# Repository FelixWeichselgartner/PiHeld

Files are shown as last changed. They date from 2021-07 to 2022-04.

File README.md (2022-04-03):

# PiHeld

This project is the first Raspberry Pi based handheld console to include a GameBoy cartridge reader.

The PCBs are under active testing and will a working prototype should be available soon. Be a bit more patient of you want to use the PCBs ;).

## Preview

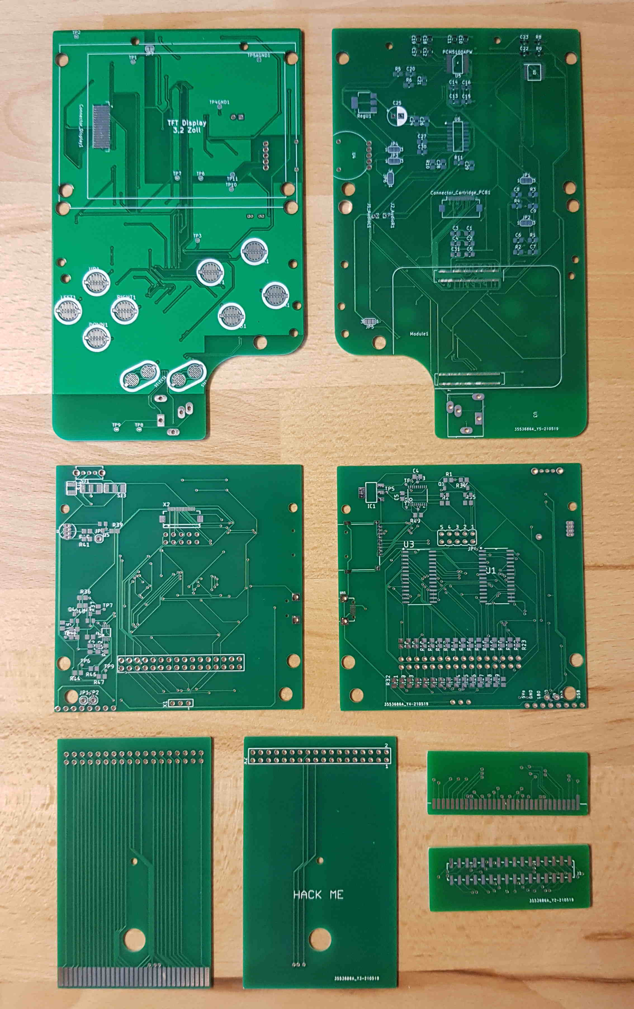
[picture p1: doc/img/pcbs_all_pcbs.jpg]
all_pcbs


## Build guide

TODO: Here include all parts and how to build the system.

## Developer information

For Documentation check out [this](./doc/).

TODO: Here include information needed for developers.

# Further improvements (to-do list):

* Add a HDMI (or Mini-HDMI) Connector to the CM4 (on display-pcb) to give the user a Nintendo Switch like experience.
* Make a version compatible with the Raspberry Pi Zero, as it is cheaper and more commonly used.
* Make a version that fits in a GameBoy Color/Pocket shell. As those only have one pcb inside, the display and cartridge pcb could be combined to a single pcb. This would make the production part significantly easier.
* Make the USB-Charging port bidirectional. This enables users to connect e.g. a keyboard to the device (USB OTG).
* Update the software to enable users to interface with GameBoy Color cartridges.
* Theoretically GameBoy Advance cartridges could also be used with the system. Maybe some minor hardware modifications would be needed for this. Also the GBA cartridges do not fit in the GB/GBC/GBP cartridge slot.
* Make a custom OS-Image that already features the needed modifications for the hardware.
* Cartridge-pcb version with MCP23S17, as SPI is a lot faster than I²C.

## License

This project is completely open source, as we want everybody to be able to build their own PiHeld. Check out the `License.md` file to get further information on licensing.

## Split-off projects

* https://github.com/FelixWeichselgartner/Arduino_Logic_Analyzer
* https://github.com/FelixWeichselgartner/Adafruit_PowerBoost_SaveShutdown
* https://github.com/FelixWeichselgartner/RPi-I2C-LevelShifter
* https://github.com/FelixWeichselgartner/rpi-mcp23017

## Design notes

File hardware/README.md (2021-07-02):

## Hardware

Just like the original GameBoy there are two pcbs on which all the components are placed.

### Mapping of the functionalities
* Display-PCB
    * Compute Module 4
    * Display
    * Audio
    * Buttons
* Cartridge-PCB
    * Connectors (MicroUSB, MicroSD, ...)
    * Power Management (LiPo, charger, ...)
    * Cartridge dumper
    * Save shutdown circuit
    * ADC for battery percentage
    * optional IC for fast level shifting

### FFC Connection

The two pcbs are connected with a ffc. This is how the 18 pins are used:
* 1 - 5V - power supply of Cartridge-PCB
* 2 - 5V - power supply of Cartridge-PCB
* 3 - 5V - power supply of Cartridge-PCB
* 4 - 5V - power supply of Cartridge-PCB
* 5 - SDA - I²C-Data of cm4
* 6 - SCL - I²C-CLK of cm4
* 7 - 3.3V - digital 3.3V power supply provided by cm4
* 8 - CD/DAT3/CS - SD-Card
* 9 - DAT2/RSV - SD-Card
* 10 - DAT1/RSV - SD-Card
* 11 - DAT0/DO - SD-Card
* 12 - CLK/SCLK - SD-Card
* 13 - CMD/DI - SD-Card
* 14 - Shutdown - shutdown signal for cm4
* 15 - GND - Ground of Cartridge-PCB
* 16 - GND - Ground of Cartridge-PCB
* 17 - GND - Ground of Cartridge-PCB
* 18 - GND - Ground of Cartridge-PCB

### Buying links

Alls links are just suggestions (mostly the parts I ordered) and may not be valid anymore. I have no affiliation to any platform linked below.

#### General
* The PCBs
* GameBoy shell: https://de.aliexpress.com/item/4001165606660.html?spm=a2g0s.9042311.0.0.27424c4dcSplCO
* FPC-Connector (18P): https://de.aliexpress.com/item/32956902542.html?spm=a2g0s.9042311.0.0.27424c4dpEIIFD
* FFC: https://de.aliexpress.com/item/10000012558629.html?spm=a2g0s.9042311.0.0.27424c4dpEIIFD
* 0805 Resistors and Capacitors

#### Cartridge-PCB
* MicroSD-Card-Adapter: https://de.aliexpress.com/item/4001278357176.html?spm=a2g0s.9042311.0.0.27424c4dHRu5rN
* MicroUSB-Adapter: https://de.aliexpress.com/item/4000774276762.html?spm=a2g0s.9042311.0.0.27424c4dHRu5rN
* LiPo-Battery: https://de.aliexpress.com/item/4000687003747.html?spm=a2g0s.9042311.0.0.27424c4dHRu5rN
* GameBoy Cartridge Adapter: https://de.aliexpress.com/item/4000290191316.html?spm=a2g0s.9042311.0.0.27424c4dcSplCO
* Power switch: https://de.aliexpress.com/item/32920574638.html?spm=a2g0s.9042311.0.0.27424c4dj7Khsc
* 2N7002: https://de.aliexpress.com/item/2029421500.html?spm=a2g0s.9042311.0.0.27424c4dj7Khsc
* RGB-LED: https://de.aliexpress.com/item/32885829414.html?spm=a2g0s.9042311.0.0.27424c4dpEIIFD
* ADS1015: https://de.aliexpress.com/item/4001177538119.html?spm=a2g0s.9042311.0.0.27424c4dpEIIFD
* Male SMD Header: https://de.aliexpress.com/item/32954771384.html?spm=a2g0s.9042311.0.0.27424c4dpEIIFD
* TXB0108PWR: https://de.aliexpress.com/item/1005001823871461.html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
* MCP23017-E/SO: https://de.aliexpress.com/item/1005001802509822.html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

#### Cartridge-PCB Tester (Optional)
* GameBoy Cartridge shell: https://de.aliexpress.com/item/1005001278227724.html?spm=a2g0s.9042311.0.0.27424c4dHRu5rN
* Male Headers with 2.54mm

#### Display-PCB
* Display: https://de.aliexpress.com/item/4000654251979.html?spm=a2g0s.9042311.0.0.27424c4dpEIIFD
* XPT2046: https://de.aliexpress.com/item/32790065511.html?spm=a2g0s.9042311.0.0.3aed4c4dYS9Rbq
* PCM5100A: https://de.aliexpress.com/item/1005002119447863.html?spm=a2g0s.9042311.0.0.3aed4c4dYS9Rbq
* Volume Wheel: https://de.aliexpress.com/item/1005001442108461.html?spm=a2g0s.9042311.0.0.27424c4dHRu5rN
* GameBoy speaker: https://de.aliexpress.com/item/33033843204.html?spm=a2g0s.9042311.0.0.27424c4dcSplCO
* Compute Module 4 Adapter: https://de.aliexpress.com/item/1005002168314176.html?spm=a2g0s.9042311.0.0.27424c4dj7Khsc
* PAM8403: https://de.aliexpress.com/item/1005001577722596.html?spm=a2g0s.9042311.0.0.27424c4dUdkYGC
* FPC-Connector for display: https://de.aliexpress.com/item/1005002212273725.html?spm=a2g0s.9042311.0.0.27424c4d8n1T4b
* Headphone jack with plug switch: https://de.aliexpress.com/item/4000465185208.html?spm=a2g0o.cart.0.0.33b33c00diKgb9&mp=1

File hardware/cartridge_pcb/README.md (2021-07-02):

# Cartridge PCB

The cartridge pcb includes the following:
* Connectors
    * Micro USB Connector
    * SD-Card Connector
* Power Management
    * Power-Switch
    * RGB-Led (charging/low-battery/fully-charged)
    * LiPo connector
    * LiPo-BoostUp connector
* Cartridge dumper
    * 2x MCP23017 for cartridge
* Save shutdown circuit
* ADC for battery percentage
* optional IC for fast level shifting

### Schematic

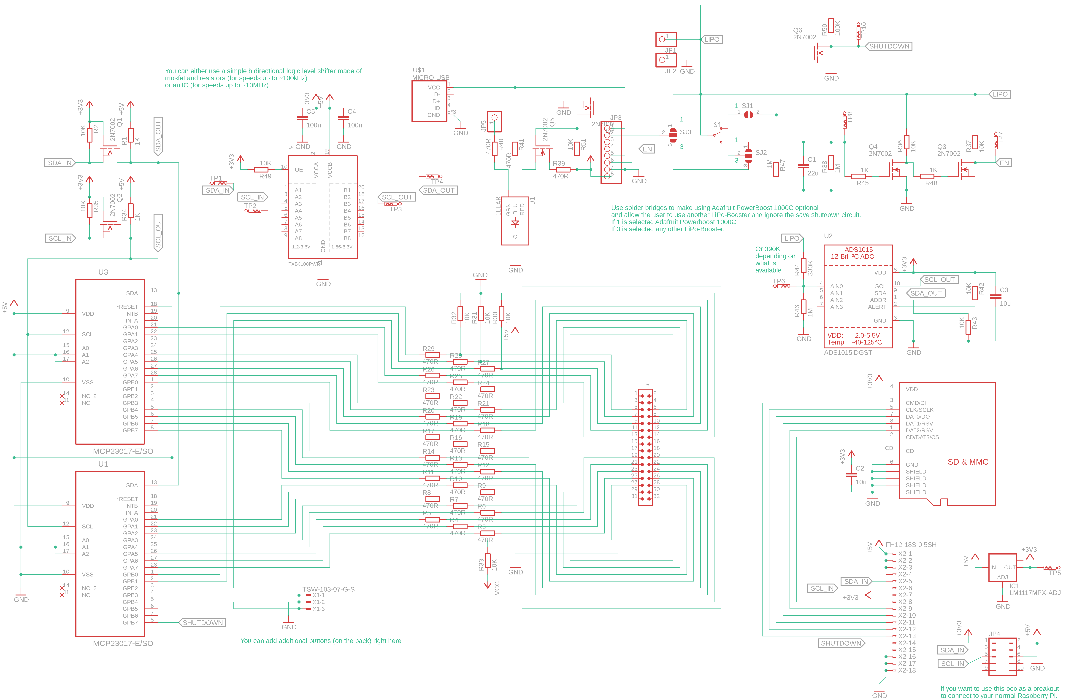
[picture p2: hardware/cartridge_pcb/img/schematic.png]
schematic


### Layout

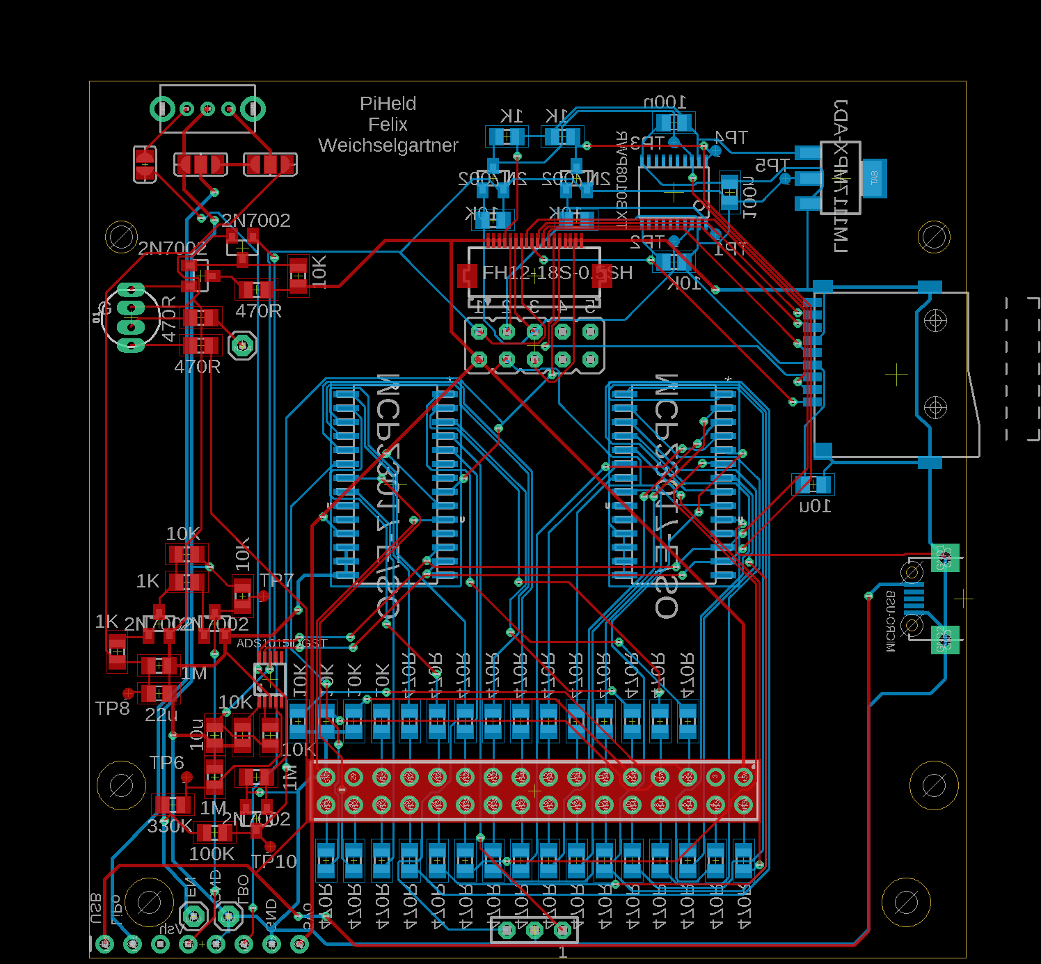
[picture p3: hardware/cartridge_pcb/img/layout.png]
layout


### Gerber Preview

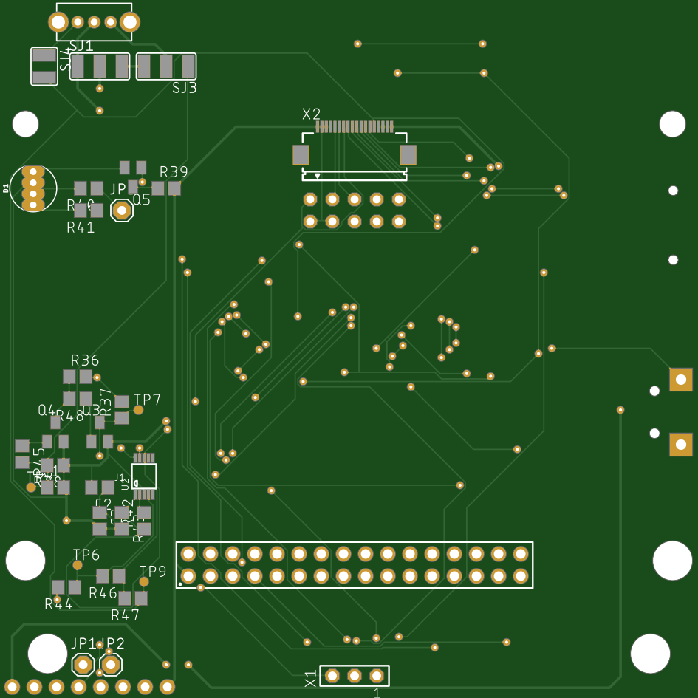
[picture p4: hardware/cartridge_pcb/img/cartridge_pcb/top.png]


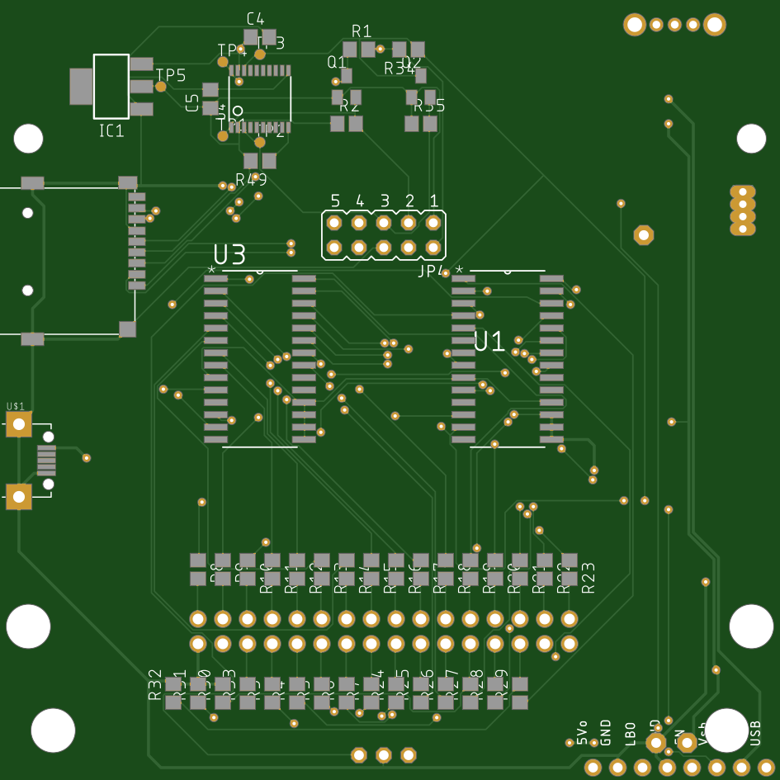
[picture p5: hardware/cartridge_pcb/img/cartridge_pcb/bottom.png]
gerber_bottom


### Breakout board for cartridge adapter to adjust height for gameboy shell

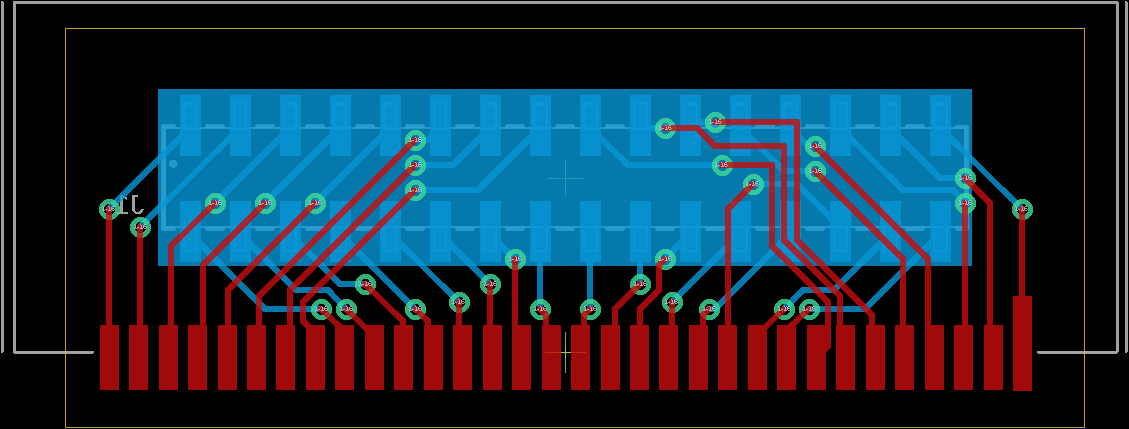
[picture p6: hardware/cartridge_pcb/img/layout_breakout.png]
layout_breakout


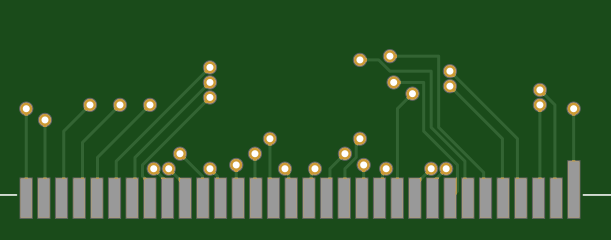
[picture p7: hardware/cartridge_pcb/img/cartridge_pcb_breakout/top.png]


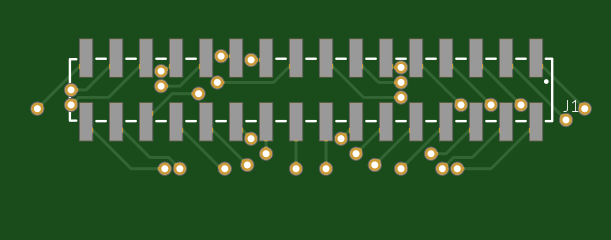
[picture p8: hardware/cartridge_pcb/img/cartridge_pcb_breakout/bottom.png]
gerber_bottom


## License

Creative Commons Attribution-ShareAlike 4.0 International License (see `LICENSE` file).

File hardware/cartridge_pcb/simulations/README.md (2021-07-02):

# Simulations

## Save Shutdown Circuit

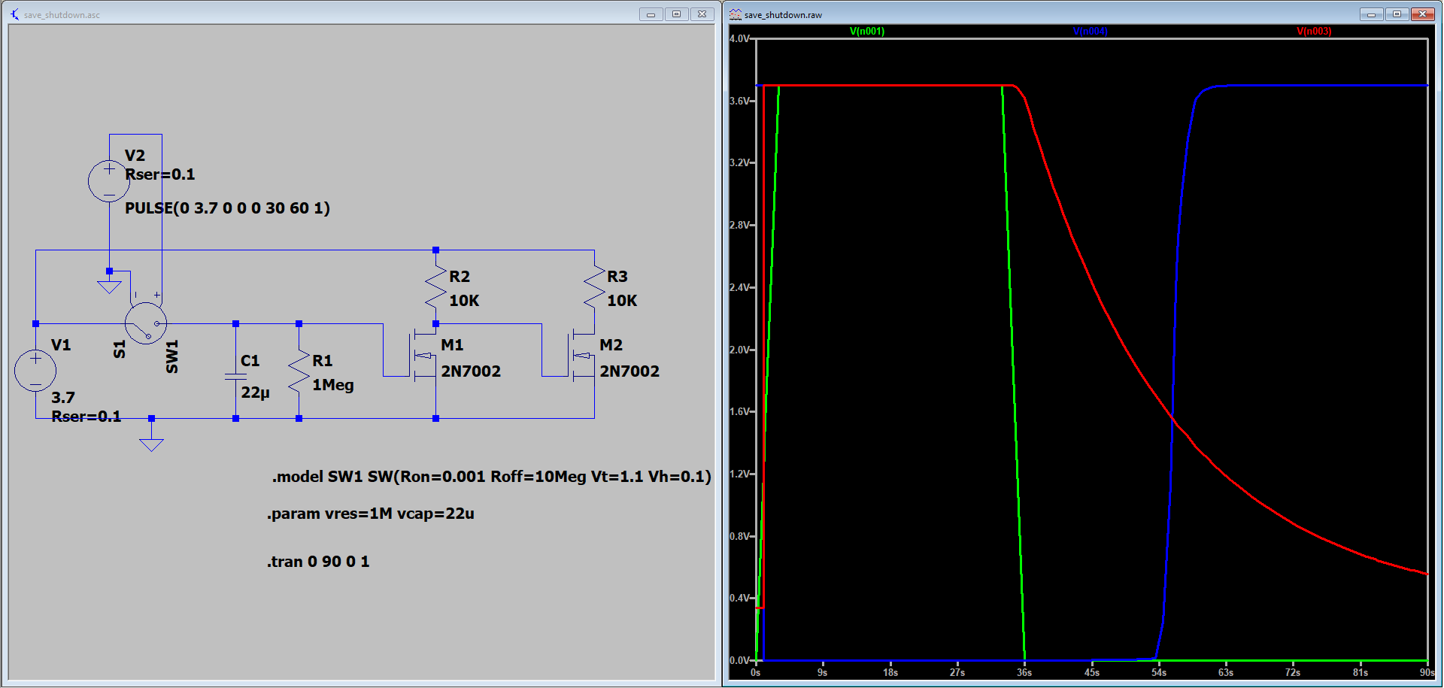
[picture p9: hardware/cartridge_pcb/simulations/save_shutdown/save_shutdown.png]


## I²C Level Shifter

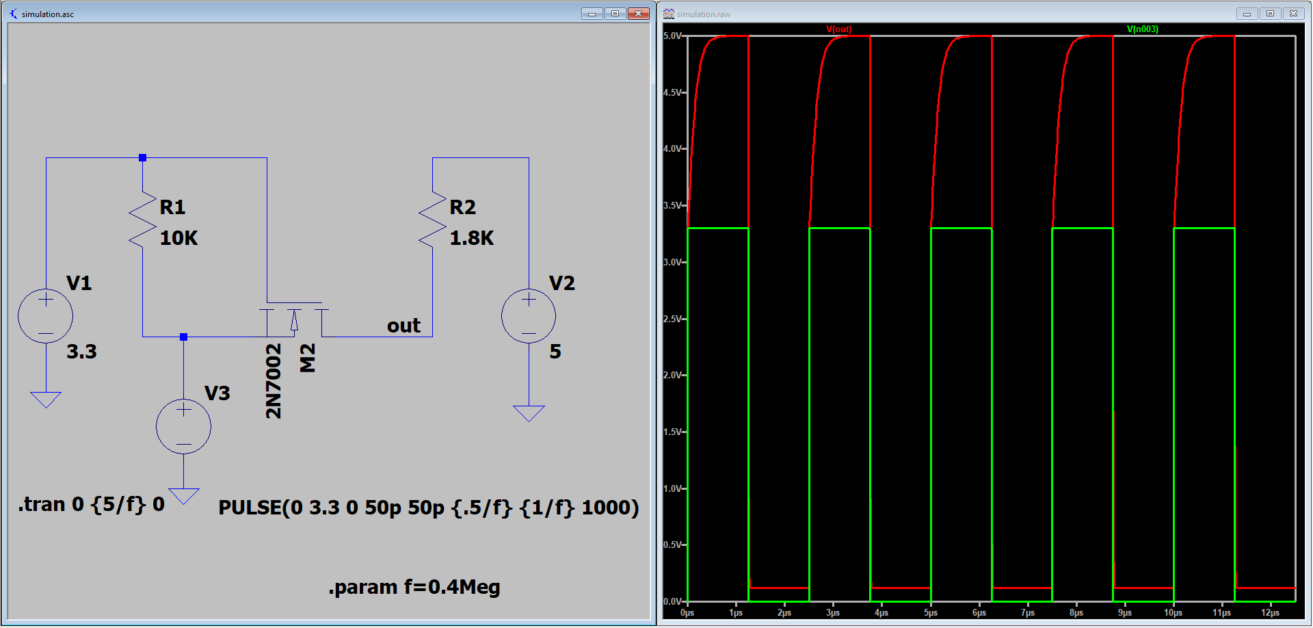
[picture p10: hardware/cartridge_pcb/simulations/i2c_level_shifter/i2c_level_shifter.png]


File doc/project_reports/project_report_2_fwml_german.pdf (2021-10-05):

# FAKULTÄT ELEKTROTECHNIK UND WIRTSCHAFTSINGENIEURWESEN

HOCHSCHULE FÜR ANGEWANDTE WISSENSCHAFTEN LANDSHUT

Projektbericht im Modul Eingebettete autonome Systeme I zum Thema

## Entwicklung einer Raspberry Pi basierten Handheld-Konsole mit eingebettetem GameBoy Cartridge Reader II

Autor: | Felix Weichselgartner, Matthias Lohberger
Betreuer: | Prof. Dr.-Ing. Mathias Rausch
Eingereicht: | 09.07.2021
Aktualisierte Version: 05.10.2021

Hiermit erklären wir, dass wir die Arbeit selbständig verfasst, noch nicht anderweitig für Prüfungszwecke vorgelegt, keine anderen als die angegebenen Quellen oder Hilfsmittel benützt sowie wörtliche und sinngemäße Zitate als solche gekennzeichnet haben.

Tiefenbach, 09.07.2021 | Felix Weichselgartner, Matthias Lohberger

## Acknowledgments

We want to thank the Open Source and GameBoy community, who made this project possible.

## Abstract

A popular project in the internet community is the „GameBoy Zero“. Here a Raspberry Pi (RPi) Zero [1] (with buttons, battery, power electronics, display, etc.) is integrated in the shell of an original GameBoy. This result in a RPi based handheld game console, that can emulate games from various systems. More about the history of the project can be found here [2]. The new contribution to the project is the embedded cartridge reader, which makes it possible to interact with real GameBoy cartridges. Therefore, it is not necessary to download ROMs from dubious websites and you are able to use your real GameBoy cartridges and emulate them, all in one device.
In this work, the design of a replacement GameBoy mainboard is continued. The pcb will be extended with components essential for an autonomous embedded system (e.g. LiPo-Battery, LiPo-Charger, Boost-Converter, ...). Furthermore, a replacement display pcb will be developed, which acts as a carrier board for a RPi Compute Module 4 (CM4). The CM4 used instead of the RPi Zero to get more calculating power, which enables the user to play more demanding games.

iii

## Inhaltsverzeichnis

Acknowledgments | ii
Abstract | iii
1 Motivation | 1
2 Grundlagen | 2
3 Implementierung | 10
4 Testen | 32
5 Ergebnisse | 34
Literaturverzeichnis | 36
Abbildungsverzeichnis | 39

iv

Inhaltsverzeichnis

Tabellenverzeichnis | 41

v

## 1 Motivation

### 1.1 Problemstellung

Ende 2018 wurde ich auf ein populäres Elektronikprojekt namens „GameBoy Zero“ [2] aufmerksam. Im Laufe der nächsten Monate, baute ich meine eigene Version [3], womit ich schlussendlich verschiedene Systeme auf einem RPi Zero [1] emulieren konnte. Der Haken ist jedoch, sofern man nicht seine eigenen GameBoy-Spiele auslesen kann, ist man auf sogenannte ROMs aus dem Internet angewiesen. Diese beinhalten den ausgelesenen Read Only Memory (ROM)-Speicher der GameBoy-Cartridges, womit das Spiel emuliert werden kann [4]. Dies führte dazu, dass ich Mitte 2019 einen Catridge-Reader [5] baute, welcher es mir ermöglichte, meine eigenen Catridges auszulesen. Hierbei kann aber nicht nur der ROM ausgelesen werden, sondern auch der Random Access Memory (RAM), welcher den Speicherstand der Spiele enthält. Das Problem hierbei ist jedoch, dass dies zwei separate Geräte und nicht wie beim originalen GameBoy in einem Gerät vereint sind.

### 1.2 Zielsetzung

In dieser Arbeit wird das Design einer Ersatzplatine des Mainboards für den Klassischen GameBoy (DMG) fortgeführt. Die Platine wird um Komponenten erweitert, welche essenziell für ein eingebettetes autonomes System sind (z.B. LiPo-Batterie, LiPo-Ladeschaltung, Aufwärtswandler, ...). Des Weiteren wird eine Ersatzplatine für die Display-Platine des DMG entwickelt, welche u.a. als Trägerplatine für ein RPi CM4 dient. Das CM4 wird anstatt eines RPi Zero verwendet, um mehr Rechenleistung für aufwändigere Spiele zur Verfügung zu haben.

1

## 2 Grundlagen

### 2.1 GameBoy

Der DMG hatte zwei Platinen. Die obere Platine (jeweils links in Abbildung 2.1) enthält im Wesentlichen das Display, Audio und die Buttons. Daher wird die Ersatzplatine im Folgenden Display-PCB genannt. Die untere Platine (jeweils rechts in Abbildung
2.1) enthält die CPU und die Cartridge-Schnittstelle. Der Ersatz für diese Platine wird daher im Folgenden Cartridge-PCB genannt.

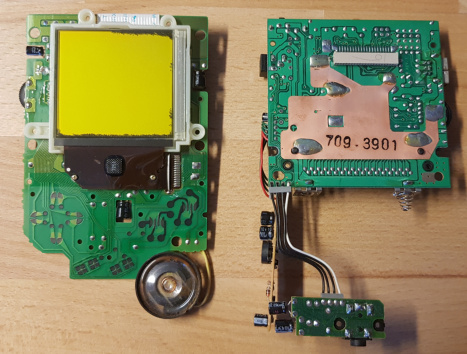
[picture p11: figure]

(a) Oberseiten der Platinen | (b) Unterseiten der Platinen
Abbildung 2.1: DMG Platinen

### 2.2 Raspberry Pi Compute Module 4

Das RPi CM4 [6] ist ein sog. „System on Module (SoM)“ welches die Kernkomponenten eines RPi auf einer kleinen aufsteckbaren Platine enthält. Sämtliche Anschlüsse für Peripheriegeräte werden auf dem sog. „Carrier-Board“ verbaut und über die Steckverbindungen leitend mit dem CM4 verbunden. Als Entwicklungsplatine wird von der Raspberry Pi Foundation das sog. „Raspberry Pi Compute Module 4 IO Board“
[7] vertrieben, welches die Spannungsversorgung, Anschlüsse für Peripheriegeräte (z.
B. HDMI, PCIe, USB, GPIO-Pins, MicroSD-Karte, ...) und weitere Funktionen enthält. Auf dieses kann das CM4 aufgesteckt werden und danach ähnlich zu einem RPi 4

2

### 2 Grundlagen

verwendet werden. Hierbei ist zu beachten, dass das CM4 nur lose auf dem RPi 4 basiert. Dementsprechend ist die Rechenleistung und Leistungsaufnahme vergleichbar, jedoch nicht identisch.

https://www.jeffgeerling.com/sites/default/files/images/raspberry-pi-model-sizecomparison.jpg

Abbildung 2.2: Vergleich verschiedener RPi Modelle [8]

In Abbildung 2.2 werden verschiedene RPi Modelle gezeigt. Neben dem bisher für den Einsatz geplanten RPi Zero W, wird das CM4 gezeigt, sowie das Vorgängermodell Compute Module 3 (CM3). Des Weiteren wird noch ein RPi 4 (Model B) gezeigt, wobei auffällt, dass dieses signifikant größer ist als die anderen Modelle (sowohl in Höhe als auch in Länge und Breite). Der wesentliche Unterschied zwischen dem Compute Module und dem RPi Zero W ist die Rechenleistung und die Leistungsaufnahme. Besonders das CM4 hat wesentlich mehr Rechenleistung als der RPi Zero W, weshalb die Leistungsaufnahme beim CM4 entsprechend höher ist. Beide Modelle wären somit für den Einsatz geeignet. Hier wurde die Entscheidung getroffen ein CM4 aufgrund der hohen Rechenleistung zu verwenden. Eine detaillierte Analyse des CM4 kann in
[8] gefunden werden.
Ein Vergleich der Rechenleistung verschiedener RPi Modelle kann in Abbildung 2.3 und ein Vergleich der Leistungsaufnahme in Abbildung 2.4 gefunden werden. In [9] werden mehrere RPi Modelle anhand verschiedener Parameter verglichen.

https://rpi-magazines.s3-eu-west-1.amazonaws.com/magpi/legacyassets/2019/06/2019-06-21-15_40_11-Window.png

Abbildung 2.3: Vergleich der Rechenleistung verschiedener RPi Modelle [9]

https://rpi-magazines.s3-eu-west-1.amazonaws.com/magpi/legacyassets/2019/06/2019-06-21-15_44_14-Window.png

Abbildung 2.4: Vergleich der Leistungsaufnahme verschiedener RPi Modelle [9]

Es fällt in Abbildung 2.4 auf, dass der RPi 4 ca. das Drei- bis Vierfache der Leistung des RPi Zero benötigt. Dementsprechend ist bei dem CM4 wesentlich geringere Akkulaufzeit zu erwarten, da der RPi den Löwenanteil der Leistungsaufnahme ausmacht. Aus Abbildung 2.3 erkannt man, dass der RPi 4 ca. die 15-fache Benchmark-Bewertung im Vergleich zum RPi Zero erhält. Mit dieser zusätzlichen Rechenleistung sollten auch rechenaufwendigere Systeme auf dem CM4 emuliert werden können.

3

### 2 Grundlagen

In diesem Projekt wird das CM4 Lite verwendet. Der Unterschied ist, dass dieses keinen embedded MultiMedia Card (eMMC)-Speicher auf der Platine verbaut hat, sondern eine externe MicroSD-Karte als Speicher für das Dateisystem verwendet. Dies gibt dem Nutzer den Vorteil den Speicher auszutauschen und ohne zusätzliche Hardware mit einem anderen Gerät auf das Dateisystem zuzugreifen.
Ein weiterer Unterschied zur Vorgängerversion ist, dass, wie in Abbildung 2.5 zu sehen ist, das CM4 jetzt durch zwei High-Density Konnektoren auf der Unterseite auf zwei entsprechende Gegenstücke aufgesteckt werden kann. Jeder der Konnektoren verfügt über 100 Pins.

https://hackster.imgix.net/uploads/attachments/1204828/image_HXdePwAR7G.png

Abbildung 2.5: Rückseite des CM4 [10]

### 2.3 Ausschaltverzögerung

Damit der Nutzer das Gerät leicht ein- bzw. ausschalten kann befindet sich auf der Oberseite ein Schalter. Um die Elektronik zu schützen (vor allem den RPi) wird mit dem Schalter nicht direkt die Stromversorgung getrennt. Stattdessen trennt der Schalter einen Kondensator mit parallel geschaltetem Widerstand von der Batteriespannung. Das RC-Glied entlädt sich infolgedessen und unterschreitet die Schaltschwelle eines Inverters. Der Ausgang dieses Inverters ist nun eine logische 1 und wird auf einen weiteren Inverter geschalten. Der zweite Inverter hat deshalb einen Ausgang von einer logischen 0. Dieser Ausgang wird nun auf den Enable-Pin der Lade- und Aufwärtswandlerschaltung (Adafruit PowerBoost 1000C [11]) gelegt. Um das Ausschalten des Nutzers zu erkennen, wird durch das Umlegen des Schalters ein großer Widerstand mit der Batteriespannung und einem GPIO-Pin des RPi verbunden. Der RPi kann durch das Überprüfen dieses Pins das Ausschalten erkennen und sich sicher herunterfahren. Dies ist besonders für das Dateisystem des RPi’s wichtig. Die Länge der Ausschaltverzögerung kann über die Werte des RC-Glieds angepasst werden. Der Schaltplan für die Ausschaltverzögerung kann in Abbildung 2.6 gesehen werden.

4

### 2 Grundlagen

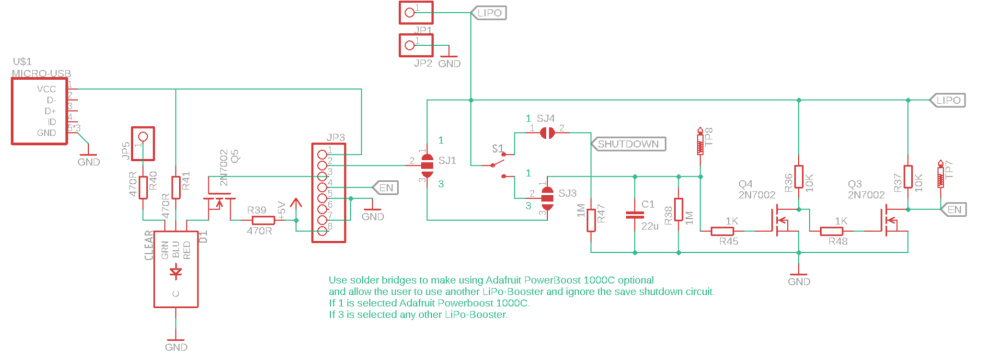
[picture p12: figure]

Abbildung 2.6: Schaltplan Ausschaltverzögerungsschaltung über RC-Glied

Mit der Schwellenspannung des Transistors und den einer RC-Konstanten von

τ = R ∗ C = 1 MΩ ∗ 22 µF = 22 s | (2.1)

ergibt sich in einer LTSpice-Simulation eine Ausschaltverzögerung von ungefähr 22s (vgl. Abbildung 2.7). Hier wird in Rot die Spannung an dem RC-Glied dargestellt, in Grün das Ausschalten des Schalters und in Blau die zweite Inverterstufe.

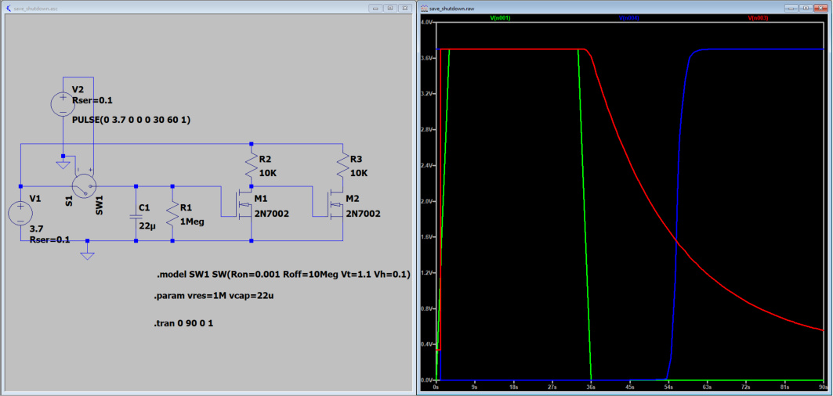
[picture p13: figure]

Abbildung 2.7: Simulation der Ausschaltverzögerungsschaltung über RC-Glied

An einer realen Schaltung konnte mit den oben genannten Werten eine Verzögerung von ca. 12s gemessen werden (vgl. Abbildung 2.8). Hier wird in Blau das Umlegen des Schalters dargestellt und in Gelb die Spannung des RC-Glieds. Mehr über das Testen der Ausschaltverzögerung kann in [12] nachgelesen werden.

5

### 2 Grundlagen

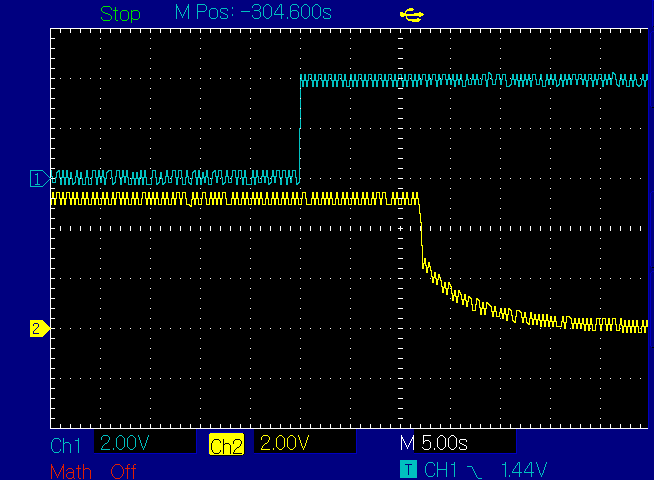
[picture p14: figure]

Abbildung 2.8

### 2.4 Pegelwandlerschaltung

Im vergangenen Semester wurde eine bidirektionale Pegelwandlerschaltung (Pws) aus MOSFETs genutzt um die 3.3V Spannungspegel der Inter-Integrated Circuit (I²C)-Leitungen des RPi’s auf 5V zu wandeln. Hiermit war eine Kommunikation mit den MCP23017-Modulen mit 100kHz ohne Probleme möglich. Die maximale I²C-Geschwindigkeit, die von den MCP23017-Modulen unterstützt wird, liegt bei 1.7 MHz. Nach dem Vermessen der Pws (siehe Abbildung 2.9, gelb Eingangsspannung, blau gewandelte Ausgangsspannung) mit unterschiedlichen Frequenzen und einer Simulation (siehe Abbildung 2.10, grün Eingangsspannung, rot gewandelte Ausgangsspannung) in LTSpice wurde klar, dass die Schaltung zu langsam für Geschwindigkeiten von 200 kHz und höher ist. Mehr über das Testen der MOSFET-Pws kann in [13] nachgelesen werden.

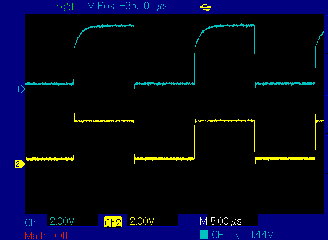
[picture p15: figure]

(a) 40 kHz | (b) 200 kHz | (c) 400 kHz
Abbildung 2.9: Geschwindigkeitsmessung der MOSFET-Pws

6

### 2 Grundlagen

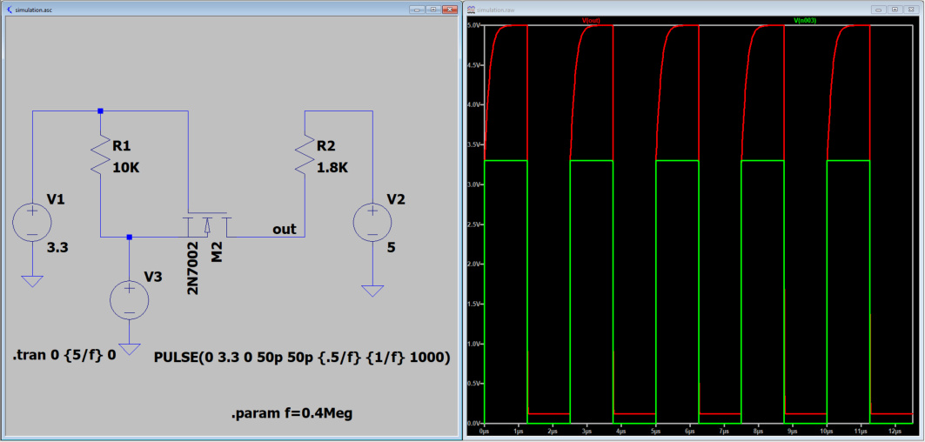
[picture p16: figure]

Abbildung 2.10: Simulation der Maximalgeschwindigkeit der MOSFET-Pws

Um dieses Problem zu lösen, wurde der Integrated Circuit (IC) TXB0108 von Texas Instruments auf der Platine verbaut. Mit dieser integrierten Schaltung sind laut Datenblatt [14] in der verwendeten Konfiguration Geschwindigkeiten von bis zu 100 Mbps möglich. Entsprechend wäre der IC auch in der Lage die Pegel für den schnelleren Serial Peripheral Interface (SPI)-Port-Expander MCP23S17 (bis zu 10 MHz) anzupassen. Bei der Schaltung (siehe Abbildung 2.11) wurde darauf geachtet, dass der Nutzer die Wahl zwischen der MOSFET-Pws oder dem TXB0108 hat, indem jeweils nur ein Teil auf der Platine eingelötet wird.

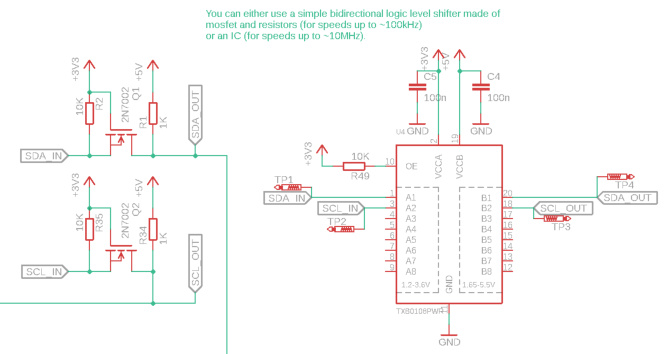
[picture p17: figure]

Abbildung 2.11: Bidirektionale Pws mit einem MOSFET und TXB0108

7

### 2 Grundlagen

### 2.5 Analoge und digitale Masse

Auf einer Platine mit analogen und digitalen Signalen sollten die jeweiligen Schaltkreise stets voneinander getrennt werden. Dem liegt zugrunde, dass digitale Chips rauschintensiv sein können und so bei kombinierten Schaltungen durch elektromagnetische Störungen die analogen Signale beeinträchtigen. Durch die Trennung der analogen und digitalen Masse entsteht allerdings das Problem der potentialfreien Masse. Denn um ordnungsgemäß zu funktionieren, sollten sich alle analogen und digitalen Chips auf dasselbe Massepotential beziehen. Die Lösung liegt hier in der Verbindung der beiden Masseflächen. Dabei gilt es wiederum Masseschleifen zu vermeiden. Eine Möglichkeit zur Reduzierung der Wahrscheinlichkeit von Masseschleifen ist die sog. Sternpunkt-Masseverbindung. Dabei werden die unterschiedlichen Masseflächen in einem einzigen, zentralen Punkt verbunden. [15]
Auf dem Display-PCB werden insbesondere für das Audio mehrere analoge Komponenten verwendet. Hinzu kommt u.a. der PCM5100, ein Digital-Analog-Umsetzer (DAC) von Texas Instruments zur Wandlung eines digitalen I²S-Signals in analoges Stereo Audio. Dieser benötigt dafür sowohl eine analoge als auch eine digitale Masse und Spannungsversorgung. Die genaue Pinbelegung kann in Abbildung 2.12 nachgelesen werden. Während DVDD und DGND digital verbunden werden müssen, ist für AVDD, AGND, CPVDD und CPGND eine analoge Spannungsversorgung bzw. Masse vorgesehen. Weitere Informationen über den PCM5100 können unter [16] nachgelesen werden.
https://www.ti.com/lit/gpn/pcm5100

Abbildung 2.12: Pinbelegung des PCM5100 Audio Stereo DAC [16]

### 2.6 Resistiver Touchscreen

Resistive Touchscreens sind eine kostengünstige Alternative zu kapazitiven Touchscreens. Letztere werden häufig in Smartphones eingesetzt und besitzen den Vorteil, dass sie mehrere Finger gleichzeitig auf dem Touchscreen erkennen können. Resistive Touchscreens hingegen sind nur in der Lage, eine einzige Berührung zu registrieren, erlauben dafür aber außer den Fingern auch die Verwendung eines Stylus o.Ä. zur Eingabe. Die Erkennung eines Single Touch funktioniert dabei wie folgt:
Abbildung 2.13 zeigt den grundsätzlichen Aufbau eines LCD-Screens mit resistivem Touch. Der Touchscreen besteht aus zwei parallelen, leitenden Flächen, die mit einem kleinen Abstand zueinander befestigt sind. Die Elektroden der oberen Schicht (Y) sind dabei um 90° gegenüber denen der unteren Schicht (X) gedreht.

8

### 2 Grundlagen

https://www.analog.com/-/media/images/analog-dialogue/en/volume-45/number-2/articles/gesture-recognition-on-resistive-touch-screens/gesturerecognition-on-resistive-t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

Abbildung 2.13: Aufbau (a) und Funktionsweise (b) eines resistiven Touchscreens [17]

Ein „Touch“ tritt auf, wenn sich die beiden Flächen durch Druck auf eine kleine Fläche des Touchscreens berühren. Wenn eine DC Spannung zwischen den beiden Elektroden der oberen Schicht angelegt wird und die untere Ebene floatet, bringt der „Touch“ die untere Ebene auf das Potential des Berührungspunkts. Die Touch-Koordinate in Richtung der oberen Schicht wird dann durch Messen der Spannung auf der unteren Fläche und Ermitteln des Verhältnisses des Widertands im Touch-Punkt zum Gesamtwiderstand bestimmt. Anschließend werden die elektrischen Verbindungen getauscht und die zweite Koordinate des Touch-Punkts auf der anderen Achse kann bestimmt werden. Die mit DC Spannung versorgte Schicht wird dabei „active-layer“ genannt, die Schicht deren Spannung gemessen wird „passive-layer“. Wenn ein Single Touch erfolgt, entsteht ein Spannungsteiler im active-layer. Durch die Spannungsmessung im passive-layer wiederum kann ein Analog-Digital-Umsetzer (ADC) die Spannung proportional zum Abstand des Touch-Punkts von der negativen Elektrode einlesen. [17]

### 2.7 I²S

In den 1980er Jahren wurde I²S von Philips Semiconductors - mittlerweile NXP - entwickelt. Das serielle Protokoll sollte die Übertragung von Stereo-Audiodaten zwischen DACs, digitalen Filtern oder anderen ICs standardisieren. Die Übertragung besteht dabei aus drei Signalen, die in Abbildung 2.14 zu sehen sind. Mit dem Serial Data (SD) Signal werden die Audiodaten mit Most Significant Bit (MSB) first in Words gesendet. Das Word select (WS) Signal gibt dazu an, ob das jeweilige Word für den rechten (WS high) oder den linken (WS low) Audio Channel bestimmt ist. Das Serial Clock (SCK) Signal gibt für den gesamten Sendevorgang den Takt vor. Insgesamt ist I²S zwar begrenzt auf Audiodaten, bietet dafür aber für diese Art der Datenübertragung eine höhere Datenrate als beispielsweise Universal Asynchronous Receiver Transmitter (UART) oder I²C. [18]

https://de.wikipedia.org/wiki/I%C2%B2S#/media/Datei:I2S_Timing.svg

Abbildung 2.14: Übertragung über I²S [19]

9

## 3 Implementierung

### 3.1 Hardware

### 3.1.1 Hardware-Aufbau

Wie auch der DMG besteht die Schaltung hier aus zwei Platinen: der Cartridge-PCB und der Display-PCB. Die Funktionen der Schaltung wurden auf die zwei Platinen wie folgt aufgeteilt:

Cartridge-PCB | Display-PCB
siehe Kapitel 3.1.2 | siehe Kapitel 3.1.3
Cartridge-Interface | CM4
Pws | Display
Lade- und Aufwärtswandlerschaltung | Audio (Verstärkung, Lautsprecher,
Ausschaltverzögerung | Kopfhörerbuchse, Lautstärkerad)
Batterieüberwachung
MicroSD-Karte

Tabelle 3.1: Aufteilung der Funktionen auf Platinen

Um Signale zwischen den Platinen auszutauschen, wurde ein flexible Flachbandkabel (ffc) mit dem dazu passenden flexible Leiterplatten (fpc)-Anschluss verwendet. Die 18-Pins wurden dabei wie folgt belegt:

10

### 3 Implementierung

Pin | Bezeichnung | Funktion
1 | 5V | Spannungsversorgung der Cartridge-PCB
2 | 5V | Spannungsversorgung der Cartridge-PCB
3 | 5V | Spannungsversorgung der Cartridge-PCB
4 | 5V | Spannungsversorgung der Cartridge-PCB
5 | SDA | I²C-Daten vom CM4
6 | SCL | I²C-Takt vom CM4
7 | 3.3V | Digitale 3.3V Spannungsversorgung vom CM4
8 | CD/DAT3/CS | SD-Karte
9 | DAT2/RSV | SD-Karte
10 | DAT1/RSV | SD-Karte
11 | DAT0/DO | SD-Karte
12 | CLK/SCLK | SD-Karte
13 | CMD/DI | SD-Karte
14 | Shutdown | Ausschaltsignal für CM4
15 | GND | Ground der Cartridge-PCB
16 | GND | Ground der Cartridge-PCB
17 | GND | Ground der Cartridge-PCB
18 | GND | Ground der Cartridge-PCB

Tabelle 3.2: Verbindungspins der Platinen

Es ist schwer genaue Angaben zu dem maximalen Strom, der über eine Leitung des ffc übertragen werden darf, zu finden. Als Richtwert wurde hier 500mA gefunden. Wie aus Abbildung 2.4 entnommen werden kann, sollte eine Leistung von bis zu 8W abgedeckt werden. Bei einer Spannung von 5V sind vier Leitungen mit jeweils 500mA ausreichend für eine Leistung von 10W. Aus diesem Grund wurden jeweils vier Leitungen für 5V und GND beim ffc verwendet.

### 3.1.2 Cartridge-PCB

Im Wesentlichen wurde die Schaltung des letzten Semesters um folgende Komponenten erweitert: Ausschaltverzögerung, schnellere Pws, Lade- und Aufwärtswandlerschaltung für LiPo-Batterie, ADC zum Überwachen der Batteriespannung und einen MicroSD-Kartensteckplatz. Weiterhin befindet sich die Schaltung zum Auslesen einer Cartridge auf der Platine. Die gesamte Schaltung kann Abbildung 3.1 entnommen werden.

11

### 3 Implementierung

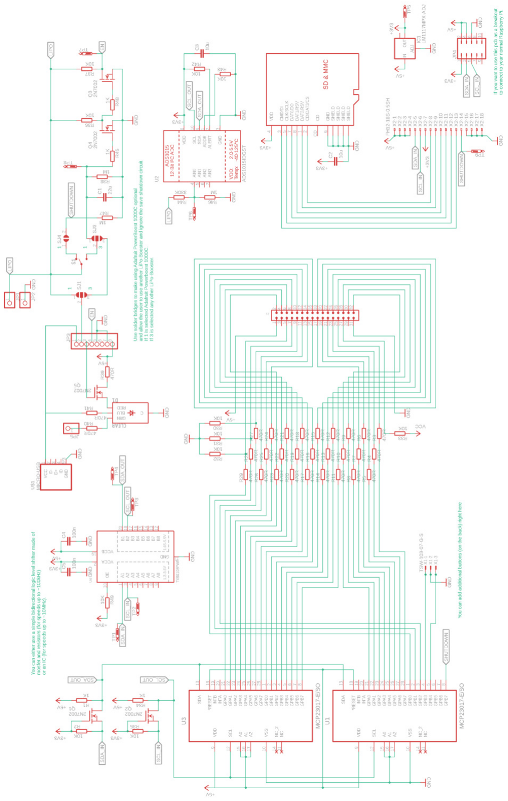
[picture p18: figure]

Abbildung 3.1: Schaltplan der Cartridge-PCB

12

### 3 Implementierung

Cartridge-Schnittstelle
Der einzige Unterschied der Cartridge-Schnittstelle ist, dass diese nun aus zwei Platinen besteht, die über eine männliche Stiftleiste verbunden werden. Dies liegt daran, dass im DMG ein höherer Cartridge-Adapter verwendet wurde. Da dieser nicht mehr gekauft werden kann, wurde ein niedrigerer Cartridge-Adapter (eigentlich für den NintendoDS) verwendet. Um die fehlende Höhe nun auszugleichen, befindet sich der Cartridge-Adapter auf einer eigenen Platine, welche über männliche Stiftleisten verbunden werden. Somit kann die Cartridge auf derselben Höhe wie beim DMG eingesteckt werden und das Bauteil passt in das DMG-Gehäuse. Das Layout der zweiten Platine kann in Abbildung 3.2 gesehen werden.
(a) Layout
(b) Platine
Abbildung 3.2: Cartridge-PCB Erweiterung

13

### 3 Implementierung

(a) Vorderansicht | (b) Unterseite

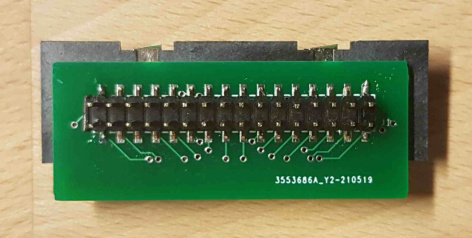
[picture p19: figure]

(c) Seitenansicht | (d) Oberseite
Abbildung 3.3: Bestückte Cartridge-PCB

Ausschaltverzögerung
In Kapitel 2.3 wurde bereits die Funktionsweise der Ausschaltverzögerung erklärt. Damit anstatt der geplanten Lade- und Aufwärtswandlerschaltung Adafruit Power-Boost 1000C [11] (welche den Enable-Pin für die Ausschaltverzögerung enthält) auch eine günstigere Schaltung verwendet werden kann, wurde die Ausschaltverzögerung optional entworfen. Mit Hilfe von drei Lötbrücken kann diese entweder aktiviert bzw. deaktiviert werden. So wird entweder eingestellt, dass der Schalter die Batteriespannung direkt trennt oder, wie in Kapitel 2.3 erklärt, über die Ausschaltverzögerung. Dies lohnt sich vor allem für Nutzer, welche nicht bereit sind, den hohen Preis von ca. 30, 00€ für den Adafruit PowerBoost 1000C zu zahlen. Vergleichbare Platinen (welche über keinen Enable-Pin verfügen) gibt es schon ab ca. 4, 00€ (vgl. Abbildung 3.4).

14

### 3 Implementierung

(a) Oberseite | (b) Unterseite
Abbildung 3.4: Adafruit PowerBoost 1000C in blau, Günstige Lade- und Aufwärtswandlerschaltung in grün

ADC für Batterieüberwachung
Um dem Nutzer die verbleibende Ladung des Akkus anzeigen zu können wurde ein ADC verbaut, mit welchem die Batteriespannung überwacht werden kann. Um Verbindungsleitungen zu sparen, wurde ein ADC mit I²C-Schnittstelle verwendet, da die I²C-Leitungen ohnehin für die MCP23017-ICs vorhanden sind.

Verbindungselemente (Schalter, MicroUSB, LED, MicroSD)
Das DMG-Gehäuse hat einige Aussparungen die für Schalter, Kontrast, Datentransfer, Lautstärkerad, Versorgungsspannung, usw. gedacht waren. Diese werden nun für andere Funktionen verwendet. Auf der Cartridge-PCB wurden hier ein Schalter, ein MicroUSB-Stecker zum Laden des Gerätes, eine MicroSD-Kartensteckplatz für das Dateisystem und eine RGB-LED zum Anzeigen des LiPo-Batteriezustandes verbaut. Da die Leitungen der MicroSD-Karte auf der Display-PCB benötigt werden, werden diese über den fpc weitergegeben (siehe Tabelle 3.2).

Platine
In Abbildung 3.5 kann das Layout der Cartridge-PCB gesehen werden.

15

### 3 Implementierung

(a) Layout

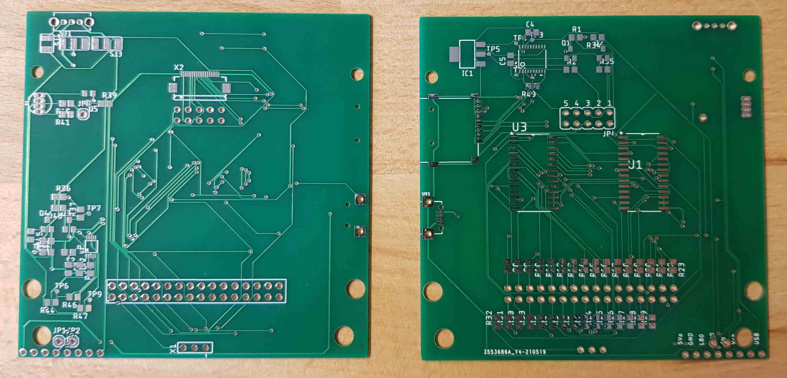
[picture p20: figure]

(b) Platine
Abbildung 3.5: Cartridge-PCB

### 3.1.3 Display-PCB

Da im Moment von RPi nur ein Footprint des CM4 für die neuste Version von KiCAD zur Verfügung gestellt wird, wurden Schaltplan und Layout des Display-PCB mit der Open Source Software in der Version 5.99 angefertigt. Die Platine basiert dabei auf dem GameBoy (GB) Projekt von Alex Hoffmann. Ein Link zu seinem GitHub Repository findet sich in [20]. Das PCB von Alex Hoffmann wurde ebenfalls in KiCAD erstellt und besaß bereits den richtigen Formfaktor mit Bohrlöchern zur Befestigung

16

### 3 Implementierung

im Gehäuse des GB. Als Herzstück diente allerdings ein RPi Zero. Da für das Display-PCB aber ein RPi CM4 ausgewählt worden ist, wurde nur die Form der Platine, einige wenige Schaltungsteile für die Buttons sowie die Positionierung der Buttons übernommen. Sämtliche anderen Schaltungen sind unabhängig von Alex Hoffmanns Version entworfen und im Layout platziert und gerouted worden.

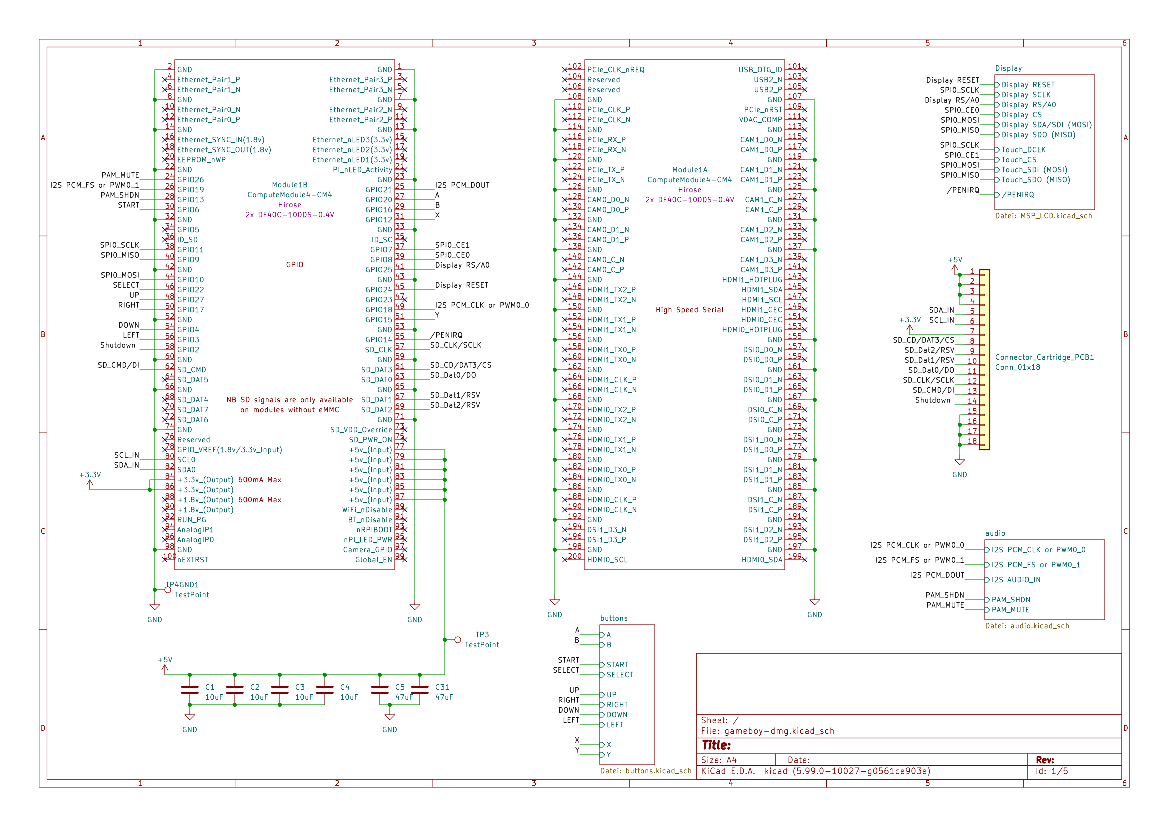
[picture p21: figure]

Abbildung 3.6: Überblick über den Schaltplan des Display-PCB - Hauptseite

17

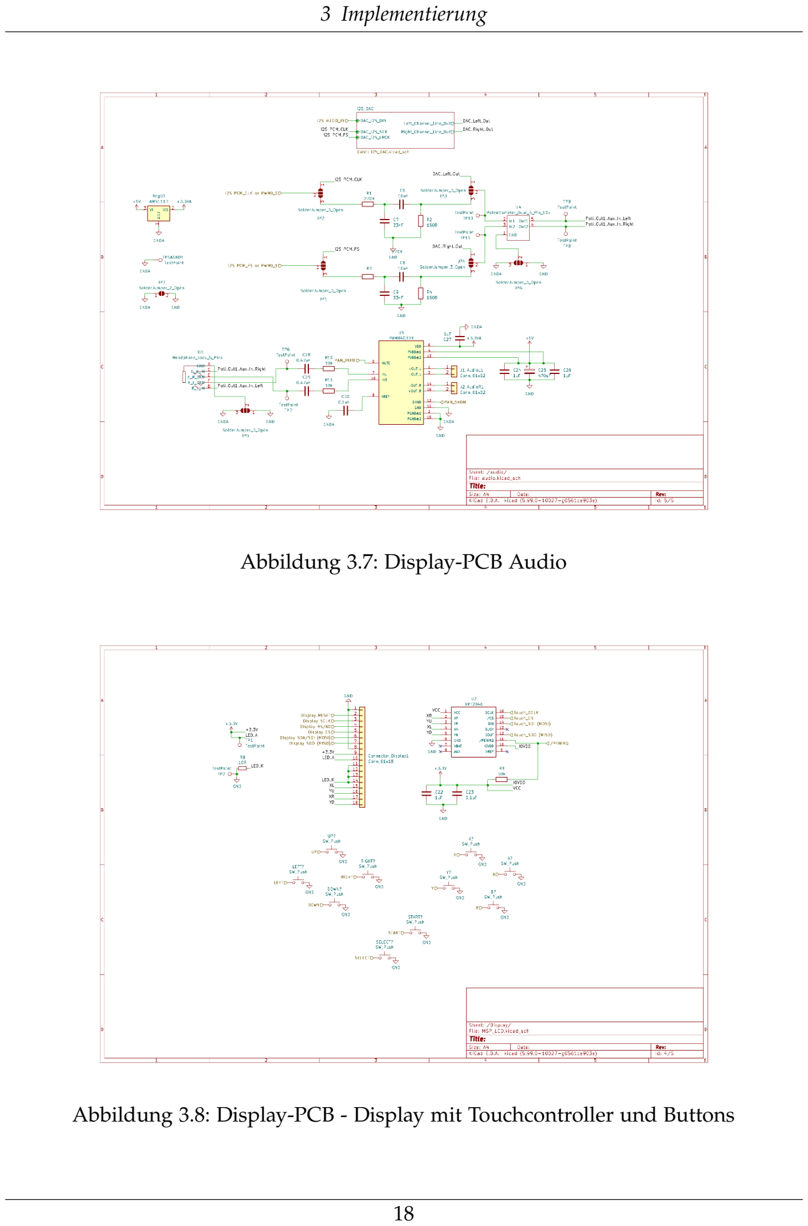
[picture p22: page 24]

### 3 Implementierung

Abbildung 3.7: Display-PCB Audio

Abbildung 3.8: Display-PCB - Display mit Touchcontroller und Buttons

18

### 3 Implementierung

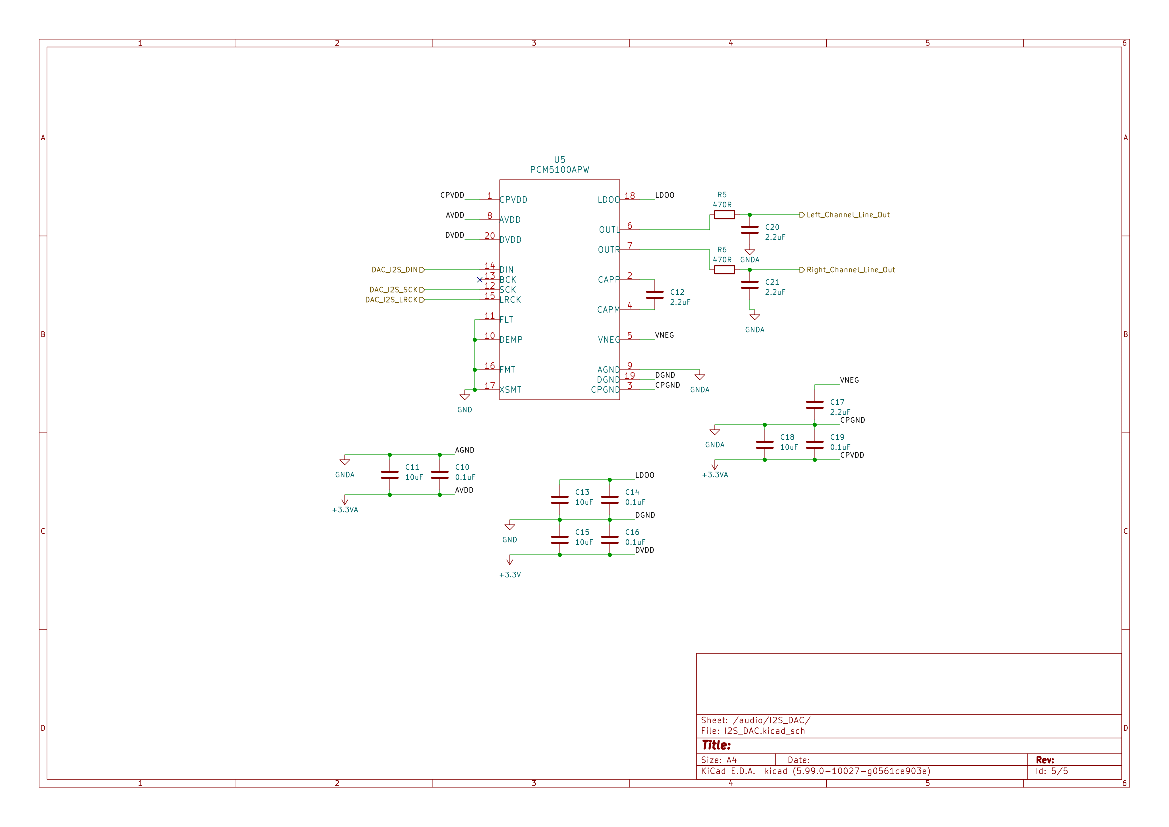
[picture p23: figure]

Abbildung 3.9: Display-PCB - Audio mit I²S

In KiCAD wird in der Regel der Schaltplan in mehrere, hierarchisch strukturierbare Schaltplanblätter gegliedert. Der Schaltplan des Display-PCB besteht daher aus vier Teilen, die alle in den vorangegangenen vier Abbildungen zusammengefasst sind. Die Hauptseite enthält die Symbole der Konnektoren des CM4, den Konnektor zum Cartridge-PCB sowie drei weiterführende Blöcke für die Seiten mit Pulsweitenmodulation (PWM) Audio, Buttons und Display. Das PWM Audio Blatt wiederum enthält eine eigene Seite für das Audio mit I²S. Aus Platzgründen sind in Abbildung ?? die Buttons beim Display enthalten.

Aufbau
Das Display-PCB ist, da es u.a. das Display beinhaltet, die oberste Platine im GB auf Basis des CM4. Alle weiteren Komponenten sind in folgender Tabelle aufgelistet:

19

### 3 Implementierung

Vorderseite | Rückseite
Display | Sockel des CM4
Display Konnektor | Touchcontroller
Pads für Conductive Rubber Buttons | Lautstärkerad
Masseflächen | Schaltungen für I²S und PWM Audio
| AUX-Buchse
| Konnektor zum Cartridge-PCB

Tabelle 3.3: Aufbau des Display-PCB

Wie bereits eingangs bereits erwähnt, wurden Formfaktor und Bohrlöcher von Alex Hoffmann größtenteils übernommen. Abbildung 3.10 zeigt den Grundriss des Display-PCB in gelber Farbe und die Position und Orientierung der wichtigsten Komponenten auf der Vorder- und Rückseite. Sämtliche Masseflächen und Leiterbahnen wurden dabei zur Übersichtlichkeit ausgeblendet. Die schwarzen Punkte überall auf dem Board sind die Bohrungen, über die die Platine in einem handelsüblichen GB Gehäuse angeschraubt werden kann. In wenigen Fällen, insbesondere durch die Platzierung des CM4, mussten einige Löcher entfernt werden. Dies bedeutet, dass auch im Gehäuse die entsprechenden Plastikstege nur als Auflage benutzt oder ganz herausgebrochen werden müssen.
Die Platine hat grundsätzlich eine rechteckige Form, die rechte untere Ecke wurde allerdings abgerundet ausgespart, da an dieser Position im GB Gehäuse der Lautsprecher vorgesehen ist. Ansonsten gibt es auf dem Display-PCB drei überstehende Komponenten. Auf der Unterseite steht die AUX-Buchse etwas über, um die Gehäuseöffnung ausfüllen zu können. Dasselbe gilt für das Lautstärkerad etwa in der Mitte der rechten Seite. Zudem wurde das das CM4 etwas überstehend platziert. Die beiden Sockel sind dabei nach wie vor auf der Platine, jedoch ragt die untere rechte Ecke des CM4 etwas über die Aussparung des Display-PCB rechts unten, um möglichst viele Bohrlöcher erhalten zu können.

20

### 3 Implementierung

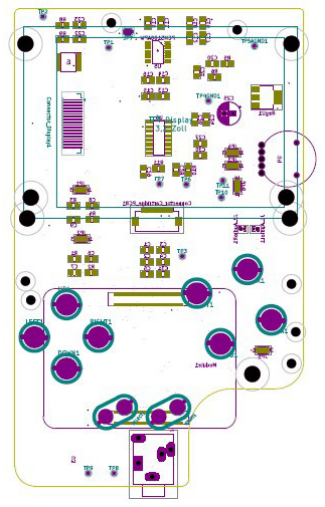
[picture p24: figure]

Abbildung 3.10: Formfaktor des Display-PCB

Audio
Für das Audio sind auf dem Display-PCB zwei verschiedene Varianten vorgesehen. Zunächst sollte wie in der Vorgängerversion von Felix Weichselgartner die Tonausgabe über PWM möglich sein. Als Alternative dazu sollte zudem I²S für das Audio verwendet werden können. Als Ausgänge wurden dafür sowohl eine 3,5mm Klinkenbuchse als auch ein Mono-Lautsprecher vorgesehen.
Für das PWM Audio wird das PWM0 Modul mit den folgenden General Purpose Input Output (GPIO) Pins verwendet:
CM4 Pin | Name | Funktion
GPIO 18 | PWM0-0 | linker Audio Channel
GPIO 19 | PWM0-1 | rechter Audio Channel

Tabelle 3.4: Pins für PWM Audio am CM4

Jeder der beiden Kanäle verfügt über einen Bandpass, wie er in Abbildung 3.11 zu sehen ist, um Rauschen und andere Störgeräusche aus dem Audiosignal herauszufiltern.

21

### 3 Implementierung

Der zugehörige Frequenzgang ist in Screenshot 3.12 gezeigt. Als Vorlage wurde dabei Quelle [21] verwendet.

Abbildung 3.11: Bandpass-Filterschaltung für das PWM Ausgangssignal am CM4

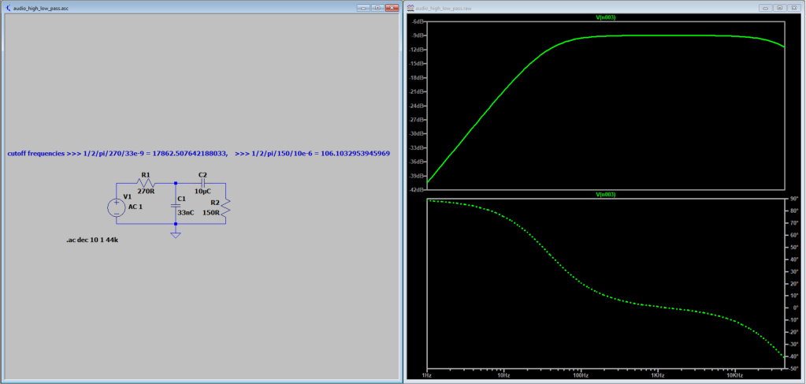
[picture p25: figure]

Abbildung 3.12: Frequenzgang der Bandpass-Filterschaltung aus LTspice

Die Grenzfrequenzen des Bandpasses berechnen sich durch die Dimensionierung wie folgt:

fg,H =

1

2π ∗ R ∗ C

=

1
2π ∗ 270 Ω ∗ 33 nF
≈ 18 kHz | (3.1)

fg,L =

1

2π ∗ R ∗ C

=

1
2π ∗ 150 Ω ∗ 10 µF
≈ 100 Hz | (3.2)

Das Audiosignal von I²S ist im Gegensatz zum PWM digital. Wie in Kapitel 2.7 bereits erklärt wurde, stellt I²S nur ein Protokoll dar. Die tatsächliche Ausgabe erfolgt am CM4 durch das Puls-Code-Modulation (PCM) Modul über die folgenden Pins:

22

### 3 Implementierung

CM4 Pin | Name | I²S Funktion
GPIO 18 | PCM-CLK | SCK
GPIO 19 | PCM-FS | WS
GPIO 21 | PCM-DOUT | SD

Tabelle 3.5: Pins für I²S Audio am CM4

Auffällig ist hierbei, dass die GPIO Pins 18 und 19 bei I²S und PWM verwendet werden. Dies ist der Mehrfachbelegung der GPIO Pins bei RPi geschuldet. Die einzelnen GPIO Pins können dabei über die Software, genauer gesagt über das config.txt File oder das Terminal für teilweise fünf verschiedene Einsatzzwecke konfiguriert werden. Auf den dazu notwendigen Code wird in Kapitel 3.2 ausführlich eingegangen. Eine detaillierte Tabelle für die alternativen Funktionen der GPIO Pins findet sich in [6]. Der Vorteil hier ist in jedem Fall, dass für die beiden Audiovarianten keine Pins verschwendet werden.
Das digitale I²S Signal ist das Eingangssignal für den PCM5100 Audio Stereo DAC. Dieser wandelt die I²S-Daten in zwei analoge Signale für den linken sowie den rechten Kanal eines Audioendgeräts. Er benötigt für die Wandlung, wie schon in Kapitel 2.5 angesprochen, sowohl eine analoge als auch eine digitale Masse und Spannungsversorgung. Aus diesem Grund wurde für den PCM5100 und einige weitere analoge Audiokomponenten mit dem AMS1117 Spannungswandler von Advanced Monolithic Systems Inc. eine eigene Versorgung mit 3,3V eingerichtet. Zusätzlich befinden sich diese Komponenten auf einer eigenen analogen Massefläche (AGND). Diese wiederum wurde nur in einem einzigen Punkt mit der normalen Massefläche für alle restlichen Bauteile verbunden. Die rudimentären Grundlagen für getrennte digitale und analoge Masse wurden bereits in Kapitel 2.5 behandelt. Für das Display-PCB ergibt sich daher folgende Aufteilung:

23

### 3 Implementierung


Abbildung 3.13: Masseflächen auf dem Display-PCB

Die Massefläche der digitalen Schaltkreise ist dabei blau umrandet, die analoge Masse wurde orange markiert. Nur über die violette Solder Bridge kann eine Verbindung zwischen den Masseflächen hergestellt werden.
Hardwareseitig erfolgt die Auswahl darüber, ob das Audio über I²S oder PWM verwendet werden soll, über Solder Bridges mit drei Kontakten. Zwei solche Brücken befinden sich an den Ausgängen der GPIO Pins 18 und 19 des CM4, um, wie bereits in Tabellen 3.4 und 3.5 verdeutlicht wurde, die verschiedenen Funktionen dieser Pins nutzen zu können. Falls softwareseitig das Audio über PWM konfiguriert ist, werden die Eingänge der beiden Solder Bridges mit den Ausgängen verbunden, die zu den Filtern für den rechten und linken Kanal des PWM Audio führen. Ist I²S am CM4 eingestellt, so können die Eingänge der beiden Solder Bridges mit den verbleibenden Ausgängen verbunden werden. Diese führen dann zu den Eingängen des PCM5100 Audio Stereo DAC. Für den dafür benötigten Code wird an dieser Stelle noch einmal auf das Kapitel 3.2 verwiesen.
Nach den Filtern bzw. dem Audio Stereo DAC muss das entsprechende Audio mit den Ausgängen, das heißt mit dem Potentiometer zur Lautstärkeregelung und in der Folge mit der AUX-Buchse und dem Lautsprecher verbunden werden. Hierfür sind

24

### 3 Implementierung

wieder zwei Solder Bridges mit jeweils 3 Kontakten, wie in Abbildung 3.14 gezeigt, vorgesehen. Mit diesen können wahlweise der linke und rechte Kanal des PWM Audios oder der linke und rechte Kanal des PCM5100 Audio Stereo DAC mit einem Dual-Potentiometer zur Lautstärkeregelung verbunden werden.


Abbildung 3.14: Solder Bridges vor dem Dual-Potentiometer

Mit einem Dual-Potentiometer lässt sich die Lautstärke zweier Audiosignale, in diesem Fall linker und rechter Kanal, mit nur einer Drehbewegung am Lautstärkerad regeln. Durch die Solder Bridges können beide Audioquellen mit dem Dual-Potentiometer verbunden und geregelt werden.
Die Ausgänge des Dual-Potentiometer führen auf eine 5-polige AUX-Buchse. Diese verfügt über zwei Pins mehr als eine gewöhnliche Klinkenbuchse. Zur Erklärung sind in Abbildung 3.15 das Symbol, die Pins auf der Unterseite der Buchse und ein 3,5mm Klinkenstecker abgebildet. Darunter die Bedeutungen der Bezeichnungen in Tabelle 3.6 festgehalten.

https://www.distrelec.de/Web/Downloads/he/et/ST-3519_en_datasheet.pdf

Abbildung 3.15: 5-polige Klinkenbuchse [22]

25

### 3 Implementierung

Pin Funktion
A Masse
B linker Kanal
C rechter Kanal
E Öffner Kontakt rechter Kanal F Öffner Kontakt linker Kanal

Tabelle 3.6: Bezeichnungen der 5-poligen AUX-Buchse

Die 5-polige AUX-Buchse zeichnet sich durch zwei mechanische Öffner für den linken und den rechten Audiokanal aus. Das bedeutet, falls kein AUX-Stecker eingesteckt ist, die Pins C und E bzw. B und F verbunden sind und die Audiosignale weitergegeben werden können. Wie in Abbildung 3.16 zu sehen ist, sind die Pins E und F der 5-polige AUX-Buchse mit den Eingängen für linken und rechten Audiokanal des PAM8403 Audio Amplifiers verbunden. Dieser verstärkt die Audiosignale für einen Mono Lautsprecher. Ist jedoch ein Kopfhörer o.ä. in der Klinkenbuchse eingesteckt, dann wird die Verbindung zum Amplifier und damit zum Mono Lautsprecher unterbrochen und die Musik wird nur über die Klinke ausgegeben. Wichtig zu erwähnen ist dabei, dass die Lautstärke in jedem Fall durch das Potentiometer geregelt werden kann, da dieses sich vor diesen Komponenten in der Schaltung befindet.


Abbildung 3.16: Verschaltung von Klinkenbuchse und PAM8403 Amplifier

Ist kein Klinkenstecker eingesteckt, erhält, wie bereits angesprochen, der PAM8403, ein 3W class-D Stereo Audio Amplifier von Power Analog Microelectronics Inc., die Audiosignale für rechten und linken Kanal. Von dessen Stereo-Ausgangssignal wird nur das Audio für den rechten Kanal verwendet, da aus Platzgründen nur ein Mono Lautsprecher für den GB vorgesehen ist. Trotzdem wurde auf dem Display-PCB die Möglichkeit vorgesehen, einen zweiten Lautsprecher für den linken Channel anzulöten.

26

### 3 Implementierung

Display
Als Display kommt ein 3,2 Zoll SPI TFT LCD-Display mit einer Auflösung von 240 x 320 Pixeln zum Einsatz. Dieses verfügt außerdem über einen resistiven Touchscreen. Das LCD-Display kann über ein Flachbandkabel mit 18 Pins bei einem Pitch von 0,8mm am Display-PCB angeschlossen werden. Die Anzeige wird dabei über das SPI0 Modul des CM4 angesteuert. Die Belegung der GPIO Pins am CM4 sieht dafür wie folgt aus:
CM4 Pin | Name | Funktion
GPIO 7 | SPI0-CE1-N | Chip Enable (CE)1 für Touchscreen
GPIO 8 | SPI0-CE0-N | CE0 für Display
GPIO 9 | SPI0-MISO | Master Input Slave Output (MISO)
GPIO 10 | SPI0-MOSI | Master Output Slave Input (MOSI)
GPIO 11 | SPI0-SCLK | Serial Clock (SCLK)

Tabelle 3.7: Pins des SPI0 Moduls am CM4

Des Weiteren werden zwei Spannungsversorgungen für die Anzeige bzw. für die LEDs der Hintergrundbeleuchtung sowie ein normaler GPIO Pin für ein Reset-Signal benötigt. Der Touchscreen kann durch Spannungsmessung an den vier Pins X-Positiv (XP), X-Negativ (XN), Y-Positiv (YP) und Y-Negativ (YN) - in Abbildung 2.13 auch als X+, X-, Y+ und Y- bezeichnet - ausgelesen werden. Die Grundlagen hierzu wurden bereits in Kapitel 2.6 erklärt. Die Spannungsmessung erfordert allerdings analoge Eingangspins, über welche das CM4 nicht verfügt. Aus diesem Grund wurde zum Auslesen des Touchscreens der XPT2046 Touchscreen Controller von Shenzhen XPTEK Technology Ltd. hinzugefügt. Dieser besitzt genau die vier zuvor genannten analogen Eingänge und gibt ein SPI Signal an das CM4 weiter. Dazu wurde der XPT2046 ebenfalls mit dem SPI0 Modul verbunden. Wie in obiger Tabelle bereits festgehalten wurde, ist der Touchcontroller aber über den CE1 Pin von SPI0 erreichbar, während CE0 für die Anzeige des Displays vorgesehen ist.

Buttons
Auf der Vorderseite des Display-PCB sind insgesamt acht Pads für Conductive Rubber Buttons zum Spielen vorgesehen. Das Steuerkreuz links besteht aus Up, Down, Left und Right. An der Unterseite befinden sich Doppel-Pads für Start und Select. Rechts befinden sich beim GB eigentlich nur die Tasten A und B. Um aber auch andere Spiele auf dem Emulator spielen zu können, wurden auch Pads für die Buttons X und Y hinzugefügt. Für diese beiden muss jedoch das Gehäuse an der entsprechenden Stelle aufgebohrt werden.

27

### 3 Implementierung


Abbildung 3.17: Buttons

### 3.2 Software

### 3.2.1 Cartridge-Reader

Die Software blieb im Wesentlichen unverändert und nur kleine Änderungen wurden vorgenommen, welche die Geschwindigkeit des Auslesens der Cartridge beschleunigen sollen.
Zum Ansteuern der MCP23017-ICs wurde im letzten Semester die WiringPi-GPIO-Bibliothek [23] für den RPi verwendet. Diese nutzt nicht alle Funktionen des MCP23017 aus, weshalb jeder Pin einzeln angesteuert (beschrieben oder gelesen) werden muss und nicht ein ganzer Port (8 Pins) auf einmal beschrieben werden kann. Dies dauert erheblich länger. Bisher konnte noch keine OpenSource-Bibliothek gefunden werden, welche diese Funktionen auf einem RPi in der Programmiersprache C oder C++ bietet. Trotzdem konnte die Geschwindigkeit signifikant verbessert werden. Wie bereits erwähnt, wird wesentlichen Anteil der Zeit wird für das Setzen der Adress-Pins benötigt. Bisher wurde hier jeder Pin jedes Mal neu gesetzt und nicht darauf geachtet ob sich die Pins überhaupt ändern. Der Code wurde nun so geändert, dass die letzte Adresse gespeichert und überprüft wird, ob sich der Pin von der letzten zur aktuellen Adresse ändert. Ändert er sich nicht wird kein Befehl and das I²C-Modul geschickt und die Zeit kann gespart werden. Dies reduziert die benötigte Zeit zum Auslesen einer Cartridge auf ca. 50%.

28

### 3 Implementierung

✈♦✐❞ ●P■❖✿✿s❡t❆❞❞r❡ss✭❲♦r❞ ❛❞❞r❡ss✮ ④
❢♦r ✭✐♥t ✐ ❂ ✵❀ ✐ ❁ ✶✻❀ ✐✰✰✮ ④
✴✴ t❤✐s r❡❞✉❝❡❞ t❤✐s t✐♠❡ ♥❡❡❞❡❞ ❢♦r ❝❛rtr✐❞❣❡ r❡❛❞✐♥❣ ❛❜♦✉t ✺✵✪ ✴✴ ❛s ✇❡ ♦♥❧② ♥❡❡❞ t♦ ✇r✐t❡ ✐❢ t❤❡ ♣✐♥ ❛❝t✉❛❧❧② ❝❤❛♥❣❡❞✳
✐❢ ✭✭✭❛❞❞r❡ss ✫ ✵①❋❋❋❋✮ ✫ ✭✶ ❁❁ ✐✮✮
✦❂ ✭✭❧❛st❆❞❞r❡ss ✫ ✵①❋❋❋❋✮ ✫ ✭✶ ❁❁ ✐✮✮✮ ④ ❞✐❣✐t❛❧❲r✐t❡✭
❜❛s❡❴✐♦❴❡①♣❛♥❞❡r❴❛❞❞r❡ss ✰ ✐✱
✭✭❛❞❞r❡ss ✫ ✵①❋❋❋❋✮ ✫ ✭✶ ❁❁ ✐✮✮ ❂❂ ✭✶ ❁❁ ✐✮ ✮❀
⑥
⑥

❧❛st❆❞❞r❡ss ❂ ❛❞❞r❡ss❀
⑥
Abbildung 3.18: Setzen einer Adresse

Um die Geschwindigkeit weiter zu erhöhen kann die Geschwindigkeit des I²C-Bus erhöht werden. Da die I²C-Befehle einen Großteil der Zeit ausmachen, kann durch ein Verdoppeln der Geschwindigkeit die benötigte Zeit fast halbiert werden. Die maximale Baudrate des MCP23017 ist 1, 7MHz, wohingegen bisher eine Baudrate von 100kHz verwendet wurde. Somit sollte hiermit die Zeit um erneut mehr als 90% verkürzt werden können. Um die hohe Baudrate von 1, 7MHz nutzen zu können wurde, wie in Kapitel 2.4 erklärt, ein IC für die Pegelwandlung auf der Platine verbaut. Die I²C-Geschwindigkeit kann in der „/boot/config.txt“-Datei des RPi-Dateisystems mit dem folgenden Befehl verändert werden:

❞t♣❛r❛♠❂✐✷❝❴❛r♠❂♦♥✱✐✷❝❴❛r♠❴❜❛✉❞r❛t❡❂✶✼✵✵✵✵✵

Hiermit sollte das Auslesen von einer ROM-Bank in ca. 12s möglich sein, was bisher eine Zeit von 4min benötigt hat. Durch das Ansteuern eines ganzen Ports auf einmal, mit einer geeigneten Bibliothek, sollte es möglich sein an die Zeit des Arduino Shields
[24] von 7, 7s anzuschließen. Mit der SPI-Version des MCP23017 (MCP23S17) wäre es denkbar, dass die Zeit sogar unterboten werden kann.

29

### 3 Implementierung

### 3.2.2 Display-PCB

Um beim CM4 einen Touchscreen mit SPI ansteuern und Audio über I²S bzw. PWM ausgeben zu können, müssen einige weitere Konfigurationen softwareseitig vorgenommen werden. Ausprobiert wurden diese Einstellungen auf einem RPi Model 3B+ mit Raspberry Pi OS in der Version 5.10, da zum Testzeitpunkt das Display-PCB noch nicht gefertigt wurde und daher kein Sockel zum Aufstecken des CM4 zur Verfügung stand. Da RPi über die verschiedenen Modelle ihrer Einplatinenrechner die Nummerierung, Bezeichnung, Anzahl sowie die Konfigurationsmöglichkeiten für SPI, I²S etc. der GPIO Pins beibehält, dürfte das im Folgenden erläuterte Vorgehen für das CM4 ebenso anwendbar sein.
Beim Audio muss selbstverständlich nur die Variante aktiviert werden, die über die speziellen Solder Bridges auf dem Display-PCB verbunden wurde. In jedem Fall muss dazu das config.txt File auf der SD-Karte, welche im Betriebssystem des RPi enthalten ist, bearbeitet werden. Für das Audio über PWM muss nach [25] nur folgende Zeile am Ende der Datei hinzugefügt werden:

❞t♦✈❡r❧❛②❂♣✇♠✲✷❝❤❛♥✱ ♣✐♥❂✶✽✱ ❢✉♥❝❂✷✱ ♣✐♥✷❂✶✸✱ ❢✉♥❝✷❂✹

Für das Audio über I²S sind nach [26] und [27] einige Schritte mehr notwendig:

★ ✶✳ ❉❡❛❦t✐✈✐❡r❡♥ ❞❡s ❉❡❢❛✉❧t ❆✉❞✐♦ ❞✉r❝❤ ❆✉s❦♦♠♠❡♥t✐❡r❡♥ ❞❡r ♥❛❡❝❤st❡♥ ★ ❩❡✐❧❡ ❞✉r❝❤ ❞❡♥ ✧★✧ ❛♠ ❆♥❢❛♥❣✿
★❞t♣❛r❛♠❂❛✉❞✐♦❂♦♥

★ ✷✳ ❊✐♥s❝❤❛❧t❡♥ ❞❡s ■✷❙ ■♥t❡r❢❛❝❡ ❞✉r❝❤ ❍✐♥③✉❢✉❡❣❡♥ ❞❡r ❢♦❧❣❡♥❞❡♥ ❩❡✐❧❡♥✿ ★■✷❙ ❉❆❈
❞t♣❛r❛♠❂✐✷s❂♦♥
❞t♦✈❡r❧❛②❂❤✐❢✐❜❡rr②✲❞❛❝
❞t❞❡❜✉❣❂✶

Nach der Bearbeitung des config.txt Files muss der RPi mit eingesteckter SD-Karte neu gestartet werden.
Um einen Touchscreen über SPI betreiben zu können, muss das config.txt File nicht verändert werden. Stattdessen ist es notwendig, auf dem RPi - mit installiertem Betriebssystem - das Terminal zu öffnen und einige Befehle auszuführen. Für das RPi Model 3B+ mit Raspberry Pi OS wurde dabei nach der Anleitung in [28] wie folgt vorgegangen:

30

### 3 Implementierung

✩ s✉❞♦ r♠ ✲r❢ ▲❈❉✲s❤♦✇
✩ ❣✐t ❝❧♦♥❡ ❤tt♣s✿✴✴❣✐t❤✉❜✳❝♦♠✴❣♦♦❞t❢t✴▲❈❉✲s❤♦✇✳❣✐t ✩ ❝❤♠♦❞ ✲❘ ✼✺✺ ▲❈❉✲s❤♦✇
✩ ❝❞ ▲❈❉✲s❤♦✇✴
✩ s✉❞♦ ✳✴▲❈❉✸✺✲s❤♦✇

In der Beschreibung des ’LCD-Show’ GitHub Repositorys von goodtft (nachzulesen in [29]) wurde vermerkt, dass für das Betriebssystem RetroPi statt den Treibern für Raspberry Pi OS, die oben durch den Download des Repositorys mit dem zweiten Befehl installiert werden, Treiber aus einem anderen Repository verwendet werden müssen. Dieses wurde in [30] verlinkt. RetroPi wiederum ist ein Betriebssystem für den RPi, welches Emulatoren für verschiedenste Konsolenspiele der älteren Generation bereitstellt und daher am Ende auch in dem im Rahmen dieser Arbeit entwickelten GB zum Einsatz kommen soll.
Da das Display durch das Flachbandkabel und die Position des zugehörigen Konnektors auf dem Display-PCB eine feste Ausrichtung besitzt, kann es u.U. notwendig sein, die Anzeige des Displays zu rotieren. Dies kann mit den folgenden Befehlen bewerkstelligt werden:

✩ ❝❞ ▲❈❉✲s❤♦✇✴
✩ s✉❞♦ ✳✴r♦t❛t❡✳s❤ ✾✵

Zur Kalibrierung des Touchscreens wird in [28] die Installation des Programms ’xinput calibrator’ mit den folgenden Befehlen empfohlen:

✩ ❝❞ ▲❈❉✲s❤♦✇✴
✩ s✉❞♦ ❞♣❦❣ ✲✐ ✲❇ ①✐♥♣✉t✲❝❛❧✐❜r❛t♦r❴✵✳✼✳✺✲✶❴❛r♠❤❢✳❞❡❜

Das Programm kann anschließend im Menü unter ’Einstellungen -> Touchscreen kalibrieren’ ausgeführt werden.

31

## 4 Testen

Im letzten Semester wurde bereits eine Platine gefertigt, mit der die Funktionalität der Cartridge-PCB überprüft werden kann. Hierbei handelte es sich um eine Vorlage [31] bei der die Pins der Cartridge mit Pads zum Anlöten von Kabeln verbunden wurden. Um das Anschließen zu beschleunigen und Fehler zu verhindern, wurde die Platine verbessert (siehe Abbildung 4.1). Auf der neuen Platine können männliche Stiftleisten eingelötet werden, womit die Platine auf einen Arduino Mega Mikrocontroller aufgesteckt werden kann (siehe Abbildung 4.2).


(a) Layout | (b) Platine
Abbildung 4.1: PCB zum Testen der Cartridge-PCB

32

### 4 Testen


(a) Einzelteile
(b) Unterseite | (c) Oberseite
(d) Eingesteckt Seitenansicht


(e) Eingesteckt Draufsicht
Abbildung 4.2: Bestückte Debug Cartridge für Arduino Mega

33

## 5 Ergebnisse

Im Laufe des Projekts wurden beide Platinen erstellt und angefertigt (vgl. Abbildung 3.3, 3.5, 5.1, 5.2). Des Weiteren wurde die Platine zum Testen der Cartridge-PCB verbessert (vgl. Abbildung 4.2). Aus zeitlich Gründen konnten nicht alle Platinen rechtzeitig bestückt und getestet werden.


(a) Layout | (b) Platine | (c) Platine
Abbildung 5.1: Cartridge-PCB mit eingestecktem Cartridge-PCB-Tester

34

### 5 Ergebnisse

(a) Vorderseite | (b) im Gehäuse
Abbildung 5.2: Display-PCB

Der weitere Verlauf des Projekts kann in [32] verfolgt werden. Hier stehen alle Projektdateien als Open-Source Projekt unter dem Namen PiHeld zur Verfügung.

35

## Literaturverzeichnis

[1] “Raspberry | Pi | Zero | W,” | https://www.raspberrypi.org/products/
raspberry-pi-zero-w/, (https://www.raspberrypi.org/products/raspberry-pi-zero-w/) Zugriff: 17.12.2020.
[2] “ZeroBoy: Geschichte,” https://www.zeroboy.eu/geschichte/, Zugriff: 05.12.2020.
[3] F. Weichselgartner, “GameBoy Zero,” https://felixweichselgartner.github.io/2019/01/29/GameBoy_Zero.html, (https://felixweichselgartner.github.io/2019/01/29/GameBoy_Zero.html) Zugriff: 12.12.2020.
[4] ——, | “GitHub: | GameBoy-Classic-Emulator,” | https://github.com/
FelixWeichselgartner/GameBoy-Classic-Emulator, (https://github.com/FelixWeichselgartner/GameBoy-Classic-Emulator) Zugriff: 07.12.2020.
[5] ——, “GB Cartridge Reader Writer,” https://felixweichselgartner.github.io/2019/09/01/GB_Cartridge_Reader_Writer.html, (https://felixweichselgartner.github.io/2019/09/01/GB_Cartridge_Reader_Writer.html) September 2019, Zugriff: 07.12.2020.
[6] “Raspberry Pi Compute Module 4,” https://datasheets.raspberrypi.org/cm4/cm4-datasheet.pdf, (https://datasheets.raspberrypi.org/cm4/cm4-datasheet.pdf) Zugriff: 07.05.2021.
[7] “Raspberry Pi Compute Module IO Board,” https://datasheets.raspberrypi.org/cm4io/cm4io-datasheet.pdf, (https://datasheets.raspberrypi.org/cm4io/cm4io-datasheet.pdf) Zugriff: 07.05.2021.
[8] J. Geerling, “The Raspberry Pi Compute Module 4 Review,” https://www.jeffgeerling.com/blog/2020/raspberry-pi-compute-module-4-review, Zugriff: 08.05.2021.
[9] R. Zwetsloot, “Raspberry Pi 4 specs and benchmarks,” https://magpi.raspberrypi.org/articles/raspberry-pi-4-specs-benchmarks, (https://magpi.raspberrypi.org/articles/raspberry-pi-4-specs-benchmarks) Zugriff: 07.05.2021.
[10] G. Halfacree, “Hands-On with the Raspberry Pi Compute Module 4 and Compute Module 4 Lite,” https://www.hackster.io/news/hands-on-with-the-raspberry-pi-compute-module-4-and-compute-module-4-lite-827bb3293ee9, (https://www.hackster.io/news/hands-on-with-the-raspberry-pi-compute-module-4-and-compute-module-4-lite-827bb3293ee9) November 2020, Zugriff: 01.07.2021.
[11] “Adafruit Powerboost 1000C - Overview,” https://learn.adafruit.com/adafruit-powerboost-1000c-load-share-usb-charge-boost, (https://learn.adafruit.com/adafruit-powerboost-1000c-load-share-usb-charge-boost) Zugriff: 22.05.2021.

36

Literaturverzeichnis

[12] F. Weichselgartner, “GitHub: Adafruit_PowerBoost_SaveShutdown,” https://github.com/FelixWeichselgartner/Adafruit_PowerBoost_SaveShutdown, Zugriff: 29.04.2021.
[13] ——, “GitHub: RPi-I2C-LevelShifter,” https://github.com/FelixWeichselgartner/RPi-I2C-LevelShifter, (https://github.com/FelixWeichselgartner/RPi-I2C-LevelShifter) Zugriff: 29.04.2021.
[14] TXB0108 8-Bit Bidirectional Voltage-Level Translator with Auto-Direction Sensing and ±15-kV ESD Protection, Texas Instruments Inc., August 2020, https://www.ti.com/lit/ds/symlink/txb0108.pdf. (https://www.ti.com/lit/ds/symlink/txb0108.pdf)
[15] Z. Peterson, “Wie Sie einen Sternpunkt für analoge und digitale
Masseverbindungen | verwenden,” | https://resources.altium.com/de/p/
how-to-use-a-star-point-for-analog-ground-digital-ground-connection, (https://resources.altium.com/de/p/how-to-use-a-star-point-for-analog-ground-digital-ground-connection) | De-
zember 2020, Zugriff: 14.06.2021.
[16] Audio Stereo DAC with 32-bit, 384kHz PCM Interface, Texas Instruments Inc., September 2012, https://www.ti.com/lit/gpn/pcm5100.
[17] J. Calpe, “AD7879 Controller Enables Gesture Recognition on Resistive
Touch | Screens,” | https://www.analog.com/en/analog-dialogue/articles/
gesture-recognition-on-resistive-touch-screens.html#, (https://www.analog.com/en/analog-dialogue/articles/gesture-recognition-on-resistive-touch-screens.html) | Juni | 2011, | Zugriff:
14.06.2021.
[18] R. Keim, “Introduction to the I2S Interface,” https://www.allaboutcircuits.com/technical-articles/introduction-to-the-i2s-interface/, (https://www.allaboutcircuits.com/technical-articles/introduction-to-the-i2s-interface/) März 2020, Zugriff: 14.06.2021.
[19] wdwd, “I²S,” https://de.wikipedia.org/wiki/I%C2%B2S#/media/Datei:I2S_Timing.svg, (https://de.wikipedia.org/wiki/I%C2%B2S#/media/Datei:I2S_Timing.svg) Juni 2020, Zugriff: 14.06.2021.
[20] A. Hoffman, “Alex Hoffman Gameboy DMG Raspberry Pi Board,” https://github.com/alxhoff/gameboy-dmg-pcb, (https://github.com/alxhoff/gameboy-dmg-pcb) April 2021, Zugriff: 06.08.2021.
[21] J. List, “Behind the Pin: How the Raspberry Pi gets its Audio,” https://hackaday.com/2018/07/13/behind-the-pin-how-the-raspberry-pi-gets-its-audio/, (https://hackaday.com/2018/07/13/behind-the-pin-how-the-raspberry-pi-gets-its-audio/) Juli 2018, Zugriff: 14.06.2021.
[22] ST-3519 - 3,5mm Stereo Jack, November 2006, https://www.distrelec.de/Web/Downloads/he/et/ST-3519_en_datasheet.pdf. (https://www.distrelec.de/Web/Downloads/he/et/ST-3519_en_datasheet.pdf)
[23] “Wiring Pi - GPIO Interface library for the Raspberry Pi: I2C: MCP23008 & MCP23017,” http://wiringpi.com/extensions/i2c-mcp23008-mcp23017/, Zugriff: 05.12.2020.

37

Literaturverzeichnis

[24] F. Weichselgartner, “GitHub: GB-Cartridge-Reader-Writer,” https://github.com/FelixWeichselgartner/GB-Cartridge-Reader-Writer, (https://github.com/FelixWeichselgartner/GB-Cartridge-Reader-Writer) Zugriff: 07.12.2020.
[25] ——, “GameBoy Zero,” https://felixweichselgartner.github.io/2019/01/29/GameBoy_Zero.html, (https://felixweichselgartner.github.io/2019/01/29/GameBoy_Zero.html) Januar 2019, Zugriff: 20.06.2021.
[26] Mirko, “Carrier board for Raspberry Pi Compute Module 4,” https://hackaday.io/project/177626-mirkopc-cm4-carrier-board, (https://hackaday.io/project/177626-mirkopc-cm4-carrier-board) April 2021, Zugriff: 20.06.2021.
[27] ——, “MirkoPC Manual - Yet another Raspberry Pi Carrier Board,” https://cdn.hackaday.io/files/1776267599550784/MirkoPC%20user%20manual%20v1.0%202021-04-14.pdf, (https://cdn.hackaday.io/files/1776267599550784/MirkoPC%20user%20manual%20v1.0%202021-04-14.pdf) April 2021, Zugriff: 20.06.2021.
[28] “3.5inch RPi Display,” http://www.lcdwiki.com/3.5inch_RPi_Display, April 2021, Zugriff: 14.06.2021.
[29] gooftft, “LCD-show,” https://github.com/goodtft/LCD-show, Juni 2021, Zugriff: 14.06.2021.
[30] lcdwiki, “LCD-show-retropi,” https://github.com/lcdwiki/LCD-show-retropie, Dezember 2021, Zugriff: 14.06.2021.
[31] “Xyl2k - Homebrew Gameboy Color Cartridge,” https://github.com/Xyl2k/Gameboy-Color-Cartridge, (https://github.com/Xyl2k/Gameboy-Color-Cartridge) Zugriff: 19.12.2020.
[32] F. Weichselgartner, “GitHub: PiHeld,” https://github.com/FelixWeichselgartner/PiHeld, (https://github.com/FelixWeichselgartner/PiHeld) Zugriff: 13.06.2021.

38

## Abbildungsverzeichnis

2.1 DMG Platinen | | 2
2.2 Vergleich verschiedener RPi Modelle [8] | | 3
2.3 Vergleich der Rechenleistung verschiedener RPi Modelle [9] | | 3
2.4 Vergleich der Leistungsaufnahme verschiedener RPi Modelle [9] . . . . | 3
2.5 Rückseite des CM4 [10] | | 4
2.6 Schaltplan Ausschaltverzögerungsschaltung über RC-Glied | | 5
2.7 Simulation der Ausschaltverzögerungsschaltung über RC-Glied | | 5
2.8 Messung der Ausschaltverzögerungsschaltung über RC-Glied | | 6
2.9 Geschwindigkeitsmessung der MOSFET-Pws | | 6
2.10 Simulation der Maximalgeschwindigkeit der MOSFET-Pws | | 7
2.11 Bidirektionale Pws mit einem MOSFET und TXB0108 | | 7
2.12 Pinbelegung des PCM5100 Audio Stereo DAC [16] | | 8
2.13 Aufbau (a) und Funktionsweise (b) eines resistiven Touchscreens [17] . | 9
2.14 Übertragung über I²S [19] | | 9
3.1 Schaltplan der Cartridge-PCB | | 12
3.2 Cartridge-PCB Erweiterung | | 13
3.3 Bestückte Cartridge-PCB | | 14
3.4 Vergleich Lade- und Aufwärtswandlerschaltung | | 15
3.5 Cartridge-PCB | | 16
3.6 Überblick über den Schaltplan des Display-PCB - Hauptseite | | 17
3.7 Display-PCB Audio | | 18
3.8 Display-PCB - Display mit Touchcontroller und Buttons | | 18
3.9 Display-PCB - Audio mit I²S | | 19
3.10 Formfaktor des Display-PCB | | 21
3.11 Bandpass-Filterschaltung für das PWM Ausgangssignal am CM4 . . . . | 22
3.12 Frequenzgang der Bandpass-Filterschaltung aus LTspice | | 22
3.13 Masseflächen auf dem Display-PCB | | 24
3.14 Solder Bridges vor dem Dual-Potentiometer | | 25
3.15 5-polige Klinkenbuchse [22] | | 25
3.16 Verschaltung von Klinkenbuchse und PAM8403 Amplifier | | 26
3.17 Buttons | | 28

39

Abbildungsverzeichnis

3.18 Setzen einer Adresse | | 29
4.1 PCB zum Testen der Cartridge-PCB | | 32
4.2 Bestückte Debug Cartridge für Arduino Mega | | 33
5.1 Cartridge-PCB | | 34
5.2 Display-PCB | | 35

40

## Tabellenverzeichnis

3.1 Aufteilung der Funktionen auf Platinen | | 10
3.2 Verbindungspins der Platinen | | 11
3.3 Aufbau des Display-PCB | | 20
3.4 Pins für PWM Audio am CM4 | | 21
3.5 Pins für I²S Audio am CM4 | | 23
3.6 Bezeichnungen der 5-poligen AUX-Buchse | | 26
3.7 Pins des SPI0 Moduls am CM4 | | 27

41

## Abkürzungsverzeichnis

❉▼● Klassischen GameBoy

●❇ GameBoy

❘❖▼ Read Only Memory

❘❆▼ Random Access Memory

■❈ Integrated Circuit

■➨❈ Inter-Integrated Circuit

❙P■ Serial Peripheral Interface

■➨❙ Inter-IC Sound

P❲▼ Pulsweitenmodulation

P❈▼ Puls-Code-Modulation

❯❆❘❚ Universal Asynchronous Receiver Transmitter

▼❙❇ Most Significant Bit

42

Tabellenverzeichnis

❲❙ Word select

❙❉ Serial Data

❙❈❑ Serial Clock

●P■❖ General Purpose Input Output

❆●◆❉ analogen Massefläche

❙❈▲❑ Serial Clock

▼❖❙■ Master Output Slave Input

▼■❙❖ Master Input Slave Output

❈❊ Chip Enable

❘P✐ Raspberry Pi

❈▼✸ Compute Module 3

❈▼✹ Compute Module 4

❡▼▼❈ embedded MultiMedia Card

✛❝ flexible Flachbandkabel

❢♣❝ flexible Leiterplatten

43

Tabellenverzeichnis

❆❉❈ Analog-Digital-Umsetzer

❉❆❈ Digital-Analog-Umsetzer

P✇s Pegelwandlerschaltung

❳P X-Positiv

❳◆ X-Negativ

❨P Y-Positiv

❨◆ Y-Negativ

44

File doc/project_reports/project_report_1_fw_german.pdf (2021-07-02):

# FAKULTÄT ELEKTROTECHNIK UND WIRTSCHAFTSINGENIEURWESEN

HOCHSCHULE FÜR ANGEWANDTE WISSENSCHAFTEN LANDSHUT

Projektbericht im Modul Eingebettete autonome Systeme II zum Thema

# Entwicklung einer Raspberry Pi basierten Handheld-Konsole mit eingebettetem GameBoy Cartridge Reader I

Autor: | Felix Weichselgartner
Betreuer: | Prof. Dr.-Ing. Mathias Rausch
Eingereicht: | 28.12.2020
Aktualisierte Version: 24.06.2021

Hiermit erkläre ich, dass ich die Arbeit selbständig verfasst, noch nicht anderweitig für Prüfungszwecke vorgelegt, keine anderen als die angegebenen Quellen oder Hilfsmittel benützt sowie wörtliche und sinngemäße Zitate als solche gekennzeichnet habe.

Tiefenbach, 28.12.2020 | Felix Weichselgartner

## Acknowledgments

I want to thank the Open Source and GameBoy community, who made this project possible.

# Abstract

A popular project in the internet community is the „GameBoy Zero“. Here a Raspberry Pi Zero [1] (with buttons, battery, power electronics, display, etc.) is integrated in the shell of an original GameBoy. This result in a RPi based handheld game console, that can emulate games from various systems. More about the history of the project can be found here [2]. The new contribution to the project is the embedded cartridge reader, which makes it possible to interact with real GameBoy cartridges. Therefore, it is not neccessary to download ROMs from dubious websites and you are able to use your real GameBoy cartridges and emulate them, all in one device.
In this work, the design of a replacement GameBoy mainboard is presented. This pcb has a cartridge adapter on it, which is accessible by gpio port expanders, which can be controlled over the I²C-interface. Furthermore, the code for interfacing with a GameBoy cartridge will be developed.

iii

# Inhaltsverzeichnis

Acknowledgments | ii
Abstract | iii
1. Motivation | 1
2. Grundlagen | 2
3. Implementierung | 12
4. Testen | 19
5. Ergebnisse | 23
Literaturverzeichnis | 25
Abbildungsverzeichnis | 27
Tabellenverzeichnis | 28
A. Anhang - Testprotokoll | 30

iv

# 1. Motivation

### 1.1. Problemstellung

Ende 2018 wurde ich auf ein populäres Elektronikprojekt namens „GameBoy Zero“ [2] aufmerksam. Im Laufe der nächsten Monate, baute ich meine eigene Version [3], womit ich schlussendlich verschiedene Systeme auf einem Raspberry Pi Zero [1] emulieren konnte. Der Haken ist jedoch, sofern man nicht seine eigenen GameBoy-Spiele auslesen kann, ist man auf sogenannte ROMs aus dem Internet angewiesen. Diese beinhalten den ausgelesenen ROM-Speicher der GameBoy-Cartridges, womit das Spiel emuliert werden kann [4]. Dies führte dazu, dass ich Mitte 2019 einen Catridge-Reader [5] baute, welcher es mir ermöglichte, meine eigenen Catridges auszulesen. Hierbei kann aber nicht nur der ROM ausgelesen werden, sondern auch der RAM, welche die Speicherstände der Spiele enthält. Das Problem hierbei ist jedoch, dass dies zwei separate Geräte und nicht wie beim originalen GameBoy in einem Gerät vereint sind.

### 1.2. Zielsetzung

Der neue Beitrag zu dem „GameBoy Zero“-Projekt ist somit das Erstellen einer Platine, welche es erlaubt eine Cartridge über einen „GameBoy Zero“ auszulesen und die Entwicklung der benötigten Software. Da ein Raspberry Pi nicht genug Pins hat, um neben dem Cartridge-Adapter auch noch Inputs etc. zu erkennen, werden die GPIO-Pins mit einem MCP23017 Port Expander [6] erweitert. Damit ein sauberer und ordentlicher Einbau der Platine möglich ist, soll diese in den physischen Abmessungen dem Mainboard des originalen GameBoys entsprechen. Der Cartridge-Adapter hat somit dieselbe Position wie beim originalen GameBoy und kann über die Schnittstelle des MCP23017 angesprochen werden.

1

# 2. Grundlagen

### 2.1. GameBoy

Im Laufe der Jahre erschienen verschiedene Versionen des GameBoys. Der erste Game-Boy hatte die Modellnummer DMG-01 und wird daher oft kurz als DMG bezeichnet. Andere Bezeichnungen sind „Originaler GameBoy“ oder auch „Klassischer GameBoy“. Die Bezeichnung DMG bezieht sich hierbei auf „Dot Matrix Game“, womit das Display des GameBoys gemeint ist. In Abbildung 2.1 (a) wird das Aussehen des DMG gezeigt. Beim Zerlegen des DMG erhält man zwei Hälften. Die Platine der untere Hälfte wird in Abbildung 2.1 (b) und (c) gezeigt. In diesem Dokument wird sich, sofern nicht anders spezifiziert, auf den DMG bezogen. In [7] wird der Hardware-Aufbau eines DMG genau analysiert.


(a) Frontansicht | (b) Logikboard Oberseite | (c) Logikboard Unterseite

Abbildung 2.1.: DMG Frontansicht und Mainboard

### 2.1.1. Funktionsweise

In dem folgenden Blockschaltbild (Abbildung 2.2) wird die grundsätzliche Funktionsweise eines DMG gezeigt.

2

2. Grundlagen

https://gbdev.gg8.se/wiki/images/0/03/Gameboy1-cpuboard.gif

Abbildung 2.2.: Blockschaltbild des DMG [8]

Hier fällt auf, dass der GameBoy mit einer Adressbreite von 16 Bits (A0-A15) und einer Datenbreite von 8 Bit (D0-D7) arbeitet (sprich 1 Byte). Die Aufteilung des Adressbereichs in Read Only Memory (ROM), Random Access Memory (RAM) und internen Speicher wird in Tabelle 2.1 gezeigt. Das Verhalten der Cartridge auf Lese- und Schreibbefehle über den Memory Bank Controller (MBC) wird in Kapitel 2.1.2 erklärt.

Start | Ende | Funktion
0000 | 3FFF | 16KB ROM Bank 00 von der Cartridge (i. d. R. fest)
4000 | 7FFF | 16KB ROM Bank 01-N von der Cartridge,
| | kann über MBC gewechselt werden (falls MBC vorhanden)
8000 | 9FFF | 8KB Video RAM (VRAM), bei DMG nur Bank 0
A000 | BFFF | 8KB External RAM von der Cartridge, falls vorhanden
C000 | CFFF | 4KB Work RAM (WRAM) Bank
D000 | DFFF | 4KB Work RAM (WRAM) bei DMG feste Bank 1
E000 | FDFF | Kopie von C000-DDFF (ECHO RAM), wird i. d. R. nicht benutzt
FE00 | FE9F | Sprite attribute table (OAM)
FEA0 | FEFF | Nicht benutzbar
FF00 | FF7F | I/O Registers
FF80 | FFFE | High RAM (HRAM)
FFFF | FFFF | Interrupts Enable Register (IE)

Tabelle 2.1.: Memory Map des DMG [8]

Die Bereiche 0000-7FFF für ROM und A000-BFFF für externen RAM zeigen hierbei auf externen Speicher auf der Catridge. Auf diese wird in Kapitel 2.1.2 genauer eingegangen.

### 2.1.2. GameBoy Catridges

Grundlegend ist festzuhalten, dass alle DMG-Cartridges mit einer Spannung von 5 V arbeiten. Des Weiteren kann sich je nach Cartridge auf dieser ein sog. MBC befinden. Dieser ermöglicht es, durch eine Schreiboperation in den reinen Lesebereich (dies wird in [9] ausführlicher erklärt), einen Speicherblock gegen einen anderen zu tauschen. Dadurch kann im sehr begrenzten Speicherbereich wesentlich mehr Speicher zur Verfügung zu gestellt werden. Natürlich kann immer nur auf eine Bank gleichzeitig zugegriffen werden.

3

2. Grundlagen

Damit der GameBoy weiß, um was für eine Cartridge es sich handelt, gibt es den sog. Cartridge Header (siehe Tabelle 2.2). Dieser befindet sich am Anfang der ROM im Bereich 0100-014F, direkt hinter den Interruptvektoren. In diesem Bereich wird unter anderem der MBC (siehe Tabelle 2.3), die ROM-Größe (siehe Tabelle 2.4) und die RAM-Größe (siehe Tabelle 2.5) spezifiziert. Diese Werte sind essenziell zum Auslesen der Cartridge, da sie die Größe und das Verhalten der Cartridge kennzeichnen.

Start | Ende | Funktion
0100 | 0103 | Einstiegspunkt i. d. R. mit "no operation"(NOP)
| | und Sprung zum Programmstart
0104 | 0133 | Nintendo Logo
0134 | 0143 | Name des Spiels
0144 | 0145 | Publisher des Spiels
0146 | 0146 | Super GameBoy Flag
0147 | 0147 | Cartridge Typ (spezifiziert welcher MBC genutzt wird)
0148 | 0148 | ROM Größe (spezifiziert
| | die Anzahl der vorhandenen ROM Banken)
0149 | 0149 | Externe RAM Größe (spezifiziert
| | die Anzahl der vorhandenen RAM Banken
014A | 014A | Ländercode
014B | 014B | I/O Registers
014C | 014C | High RAM (HRAM)
014D | 014D | Header Checksumme
014E | 014F | Globale Checksumme

Tabelle 2.2.: Memory Map des Cartridge Headers [10]

Mit Tabelle 2.3 können die auf der Cartridge verbauten Bauteile erkannt werden. „MBCX“ gibt hier den verbauten MBC an, „RAM“ bedeutet, dass ein externer RAM auf der Cartridge verbaut wurde und „Batterie“ bedeutet, dass die Spannung am RAM durch eine Batterie gehalten wird. Folglich lohnt es sich, den RAM einer Cartridge auszulesen, wenn eine Batterie vorhanden ist, da hier den entsprechende Spielstand des Nutzers abgelegt wurde.

4

2. Grundlagen
Wert | Bedeutung
00 | kein MBC, ROM ist fest
01 | MBC1
02 | MBC1 + RAM
03 | MBC1 + RAM + Batterie
05 | MBC2
06 | MBC2 + Batterie
08 | ROM + RAM
09 | ROM + RAM + Batterie
0B | MMM01
0C | MMM01 + RAM
0D | MMM01 + RAM + Batterie
0F | MBC3 + TIMER + Batterie
10 | MBC3 + TIMER + RAM + Batterie
11 | MBC3
12 | MBC3 + RAM
13 | MBC3 + RAM + Batterie
19 | MBC5
1A | MBC5 + RAM
1B | MBC5 + RAM + Batterie
1C | MBC5 + RUMBLE
1D | MBC5 + RUMBLE + RAM
1E | MBC5 + RUMBLE + RAM + Batterie
20 | MBC6
22 | MBC7 + SENSOR + RUMBLE + RAM + Batterie
FC | POCKET CAMERA
FD | BANDAI TAMA5
FE | HuC3
FF | HuC1 + RAM + Batterie

Tabelle 2.3.: Cartridge Header: Cartridge Typ [10]

Die Tabelle 2.4 gibt die Anzahl der ROM-Banken und Tabelle 2.5 die Anzahl der RAM-Banken an. Diese Werten werden später auf der Softwareebene (Kapitel 3.2) verwendet, um in einer Schleife den Cartridge-Speicher auszulesen.

5

2. Grundlagen
Wert | Bedeutung
00 | nur die 2 festen Banken → 32 KB Speicher
01 | 4 Banken → 64 KB Speicher
02 | 8 Banken → 128 KB Speicher
03 | 16 Banken → 256 KB Speicher
04 | 32 Banken → 512 KB Speicher
05 | 64 Banken (bei MBC1 nur 63 genutzt) → 1 MB Speicher
06 | 128 Banken (bei MBC1 nur 125 genutzt) → 2 MB Speicher
07 | 256 Banken → 4 MB Speicher
08 | 512 Banken → 8 MB Speicher
52 | 72 Banken → 1.1 MB Speicher
53 | 80 Banken → 1.2 MB Speicher
54 | 96 Banken → 1.5 MB Speicher

Tabelle 2.4.: Cartridge Header: ROM Größe [10]

Wert | Bedeutung
00 | Kein externer RAM vorhanden
01 | 1 Bank mit 2 KB (nutzt nicht den vollen Adressbereich aus)
02 | 1 Bank mit 8 KB
03 | 4 Banken → 32 KB Speicher
04 | 16 Banken → 128 KB Speicher
05 | 8 Banken → 64 KB Speicher

Tabelle 2.5.: Cartridge Header: RAM Größe [10]

Zum Testen wurden in diesem Projekt hauptsächlich 3 Cartridges (siehe Abbildung 2.3 und 2.4) mit verschiedenen MBC verwendet: Ohne MBC, MBC1 und MBC5.

6

2. Grundlagen


(a) kein MBC | (b) MBC1 | (c) MBC5

Abbildung 2.3.: Frontansichten der verwendeten Cartridges
(a) Tetris, (b) Yoshi’s Cookie, (c) Pokémon Trading Card Game (TCG)


(a) kein MBC | (b) MBC1 | (c) MBC5

Abbildung 2.4.: Rückansichten der verwendeten Cartridges
(a) Tetris, (b) Yoshi’s Cookie, (c) Pokémon TCG

Eine genauere Analyse einer großen Menge an Cartridges und MBC kann hier [11] gefunden werden.

7

2. Grundlagen

### 2.1.3. Cartridge Schnittstelle

In Tabelle 2.1 ist zu erkennen, dass sich der Programmspeicher auf der Cartridge (ROM) im Bereich 0000-7FFF befindet und der Cartridge RAM im Bereich A000-BFFF. Bei beiden können je nach MBC (wie in Kapitel 2.1.2 bereits erklärt) unterschiedlich viele Banken vorhanden sein.


Abbildung 2.5.: Cartridge Pinout

Diese Cartridge wird nun in einen Cartridge-Adapter gesteckt, der die Platine und die Catridge elektrisch verbindet. Der in Abbildung 2.6 gezeigte Cartridge-Adapter ist eigentlich für den NintendoDS produziert und daher in SMD-Bauweise ausgeführt worden, besitzt aber dieselbe Funktion wie die THT-Variante des DMG.

8

2. Grundlagen


Abbildung 2.6.: Cartridge Adapter

### 2.2. GPIO Port Erweiterung

Wie in Abbildung 2.5 zu erkennen ist, werden zum Auslesen einer Cartridge 27 Pins (16 Adresspins + 8 Datenpins + 3 weitere Pins = 27 Pins) benötigt. Daher wird zur Erweiterung der GPIO-Pins ein GPIO-Port-Expander (MCP23017 [6]) verwendet. Die Pins des ICs können über das I²C-Protokoll beschrieben bzw. gelesen werden.


Abbildung 2.7.: Pinout des MCP23017 [6]

Der Pin VDD wird an 3.3 V verbunden und der VSS Pin an GND. SDA und SCL werden entsprechend an die I²C-Pins des Raspberry Pi angeschlossen. Wichtig ist, dass

9

2. Grundlagen

für beide I²C-Leitungen jeweils ein Pull-Up-Widerstand zu VDD verbunden werden muss. Beim Raspberry Pi 3B+ ist bereits auf dem Board jeweils ein Pull-Up-Widerstand von 1.8 kΩ verbaut. Der Reset-Pin muss ebenfalls auf VDD verbunden werden, da der Pin low-activ ist. Bei A0, A1 und A2 kann die I²C-Adresse des IC ausgewählt werden. Hierbei steht GND für eine 0 und VDD für eine 1. Die entsprechende Adresse ergibt sich aus Formel 2.1:

a = 2016 + (A2 << 2) + (A1 << 1) + A0 | (2.1)

Die minimale Adresse ist somit 0x20 und die maximale 0x27. Entsprechend können maximal 7 MCP23017 in einem I²C-Adressbereich verwendet werden.
Die Funktionsweise des MCP23017 kann in Abbildung 2.8 entnommen werden. In den folgenden Abbildungen wird SDA immer gelb und SCL immer grün dargestellt.


Abbildung 2.8.: Blockschaltbild des MCP23017 [6]

Die Funktion des IC wurde, mit Hilfe der in Abbildung 2.9 gezeigen Schaltung überprüft. Im gesamten Projekt wurde zum Zugreifen auf die ICs die Wiring Pi [12] Bibliothek verwendet.

10

2. Grundlagen


Abbildung 2.9.: Testaufbau des MCP23017 an einem Raspberry Pi 3B+

In dem bisher gezeigten Anwendungsfall des Port-Expanders wurde für VCC immer eine Spannung von 3.3 V verwendet, da der RPi an seinen GPIO-Pins mit einer Spannung von 3.3 V arbeitet. Wie bereits in Kapitel 2.1.2 erwähnt, verwenden die DMG-Cartridges eine Spannung von 5 V, weshalb auch der MCP23017 mit dieser Spannung betrieben werden muss. Damit weiterhin eine I²C-Kommunikation möglich ist, wird zwischen den SDA- und SCL-Leitungen ein Pegelwandler benötigt. In Abbildung 2.10 wird eine einfache bidirektionale Pegelwandlerschaltung gezeigt, die im Folgenden zum Umwandeln der Spannungspegel auf dem I²C-Bus verwendet wurde. Bei dieser Schaltung haben beide Seiten das gleiche GND-Potenzial. Des Weiteren wurden auf der 5 V Seite wieder Pull-Up-Widerstände für die SDA- und SCL-Leitung in Höhe von 1 kΩ eingefügt.


Abbildung 2.10.: Bidirektionale Pegelwandlerschaltung mit einem MOSFET

11

# 3. Implementierung

### 3.1. Hardware

In der in Abbildung 3.1 zu sehenden Schaltung, wurden im Wesentlichen die GPIO-Pins des MCP23017 über einen 470 Ω Widerstand an den Cartridge Adapter verbunden. Der Widerstand verhindert hierbei einen zu hohen Kurzschlussstrom, der die Catridge beschädigen könnte. Des Weiteren sind in dieser Schaltung und in dem Layout (siehe Abbildung 3.2) bereits einige Fehler ausgebessert, die in der PCB noch vorhanden sind (siehe Abbildung 3.3, behoben durch die Drähte).


Abbildung 3.1.: Schaltplan des PCB

Da die Platine im folgenden Semester in einen GameBoy Zero eingebaut werden

12

3. Implementierung

sollte, war die Form der Platine entscheidend. Die physischen Abmessungen der Platine sind hier so gewählt, dass diese dieselbe Form wie das Mainboard eines GameBoys hat. Hierfür wurde eine Eagle-Vorlage verwendet, die das GameBoy Mainboard nachbildet [13]. Von diesem Layout wurden fast alle Bauteile gelöscht und nur die physischen Abmessungen, Bohrlöcher, Drehrad zur Lautstärkeregelung und der Schalter übernommen. Da diese Vorlage jedoch mit der „CC BY-NC-SA 2.5 CA“ [14] lizensiert wurde, welche eine kommerzielle Nutzung ausschließt, und die verbleibenden Bauteile bei der Weiterführung im nächsten Semester gegen verwendbare Bauteile ausgetauscht werden müssen, wird die Vorlage nicht mehr benötigt. Mit dem Übertragen der Schaltung in eine eigene Vorlage kann somit auch auf die Lizenz verzichtet werden. Das Layout der in Abbildung 3.1 gezeigten Schaltung, kann in Abbildung 3.2 gesehen werden.


Abbildung 3.2.: Layout des PCB

Die Schaltung wurde mit Hilfe des „PCB-Milling“-Verfahren produziert. Ein großer Nachteil dieses Verfahrens ist, dass es sehr lange dauern würde, das ganze überflüssige Kupfer zu entfernen. Aus diesem Grund wird nur das Kupfer um die Leiterbahnen herum entfernt. Dementsprechend ist es schwieriger, solch eine Platine von Hand zu löten, da kein Lötstopplack vorhanden ist, der z. B. benachbarte Leiterbahnen vor einem Kurzschluss schützen würde. Des Weiteren wurden hier alle Vias von Hand gelötet. Das Löten der SMD-Bauteile wurde vor allem durch das Verwenden von zusätzlichem Flussmittel erleichtert.

13

3. Implementierung


(a) Oberseite | (b) Unterseite

Abbildung 3.3.: Leiterplatte

Des Weiteren ist anzumerken, dass die Hardware so aufgebaut ist, dass neben DMG-Cartridges mit Softwaremodifikationen auch GameBoy Color Cartridges ausgelesen werden könnten.

### 3.2. Software

Die Software orientiert sich stark an diesem Arduino Shield [15] [5] [16] [17], welches ich Mitte bis Ende 2019 erstellte. Der wesentliche Unterschied ist, dass bei dem Arduino Shield Shift-Register bzw. die GPIO-Pins des Arduinos und hier die GPIO-Port-Expander verwendet wurden.
Abbildung 3.4 zeigt das Vorgehen zum Auslesen eines Bytes von der Cartridge. Nach dem Anlegen der Adresse an der Cartridge, werden der rd-Pin und der cs-Pin auf eine logische 0 geschaltet. Für eine Leseoperation auf den ROM-Bereich müsste der cs-Pin nicht berücksichtigt werden, da dieser nur beim RAM zum Einsatz kommt. Nach einer Verzögerung von 10 µs können die Datenleitungen ausgelesen werden und die Pins wieder auf eine logische 1 gesetzt werden.

14

3. Implementierung

Byte GPIO::getByte(Word address) { this->setAddress(address); this->rd_low();
this->cs_low();
usleep(10);

Byte val = 0x00;
for (int i = 0; i < 8; i++) {
if (digitalRead(base_io_expander_data_misc + i)) { val |= (0x01 << i);
}
}

this->rd_high();
this->cs_high();
usleep(10);

return val;
}

Abbildung 3.4.: Lesen von Bytes von der Cartridge

Abbildung 3.5 zeigt das Vorgehen zum Schreiben eines Bytes in den RAM-Speicher (oder ROM-Bereich zum Wechseln der Banken) der Cartridge. Hierfür müssen zuerst alle Datenpins als Ausgang definiert werden. Nach dem Anlegen der Adresse und des Datenbytes an der Cartridge, wird der wr-Pin auf eine logische 0 geschaltet. Nach einer Verzögerung von 10 µs kann der wr-Pin wieder auf eine logische 1 gesetzt werden.

15

3. Implementierung

void GPIO::setByte(Word address, Byte data) { this->dataOutput();

setAddress(address);
for (int i = 0; i < 8; i++) { digitalWrite(base_io_expander_data_misc + i, data & (1 << i)); }

this->wr_low();
usleep(10);
this->wr_high();
usleep(10);

this->dataInput();
}

Abbildung 3.5.: Schreiben von Bytes zur Cartridge

Zum Auslesen des ROM-Speichers kann der in Abbildung 3.6 gezeigt Code verwendet werden. Vorab wird der, in Kapitel 2.1.2 erklärte, Catridge-Header ausgelesen. Die, mittels Tabelle 2.4 ermittelte, Anzahl der ROM-Banken wird in der Variable „romBanks“ gespeichert. Nun wird in einer Schleife die gewünschte Bank ausgewählt, ausgelesen und in ein Array geschrieben. Dieses Array kann später in eine Datei abgelegt werden. Hierfür hat sich die Dateiendung „.gb“ etabliert.

16

3. Implementierung

void Cartridge::DumpROM() {
rom_array = new char[romBanks * 0x4000]; Word address = 0;

// Read number of banks and switch banks
for (Word bank = 1; bank < this->romBanks; bank++) { if (this->cartridgeType >= 5) {
// MBC2 and above
// Set ROM bank
this->gpio.setByte(0x2100, bank & 0xFF); this->gpio.setByte(0x3000,
bank > 0x100 ? 0x01 : 0x00);
} else {
// MBC1
// Set ROM Mode
this->gpio.setByte(0x6000, 0);
// Set bits 5 & 6 (01100000) of ROM bank this->gpio.setByte(0x4000, bank >> 5); // Set bits 0 & 4 (00011111) of ROM bank this->gpio.setByte(0x2000, bank & 0x1F); }
if (bank > 1) { address = 0x4000; }

for (; address <= 0x7FFF; address++) { rom_array[address + 0x4000 * (bank - 1)] = this->gpio.getByte(address);
}
}
}

Abbildung 3.6.: Auslesen von ROM

Zum Auslesen des RAM-Speichers kann der in Abbildung 3.7 gezeigte Code verwendet werden. Die mittels Tabelle 2.5 ermittelte Anzahl der RAM-Banken wird in der Variable „ramBanks“ gespeichert. Ebenfalls wird in einer Schleife die gewünschte Bank ausgewählt, ausgelesen und in ein Array geschrieben. Dieses Array kann später in eine Datei abgelegt werden. Hierfür hat sich die Dateiendung „.sav“ etabliert.

17

3. Implementierung

void Cartridge::DumpRAM() { this->gpio.getByte(0x0134);

// Does cartridge have RAM
if (this->ramEndAddress > 0) {
ram_array = new char[this->ramBanks * 0x2000];

if (cartridgeType <= 4) { // MBC1
// Set RAM Mode
this->gpio.setByte(0x6000, 1); }

// Initialise MBC
this->gpio.setByte(0x0000, 0x0A);

// Switch RAM banks
for (Byte bank = 0; bank < this->ramBanks; bank++) { this->gpio.setByte(0x4000, bank);

// Read RAM
for (unsigned int address = 0xA000; address <= this->ramEndAddress;
address++) {

ram_array[address - 0xA000 + bank * 0x2000] = this->gpio.getByte(address);
}
}

// Disable RAM
this->gpio.setByte(0x0000, 0x00); }
}

Abbildung 3.7.: Auslesen von RAM

18

# 4. Testen

Zuerst, musste überprüft werden, ob die ICs über den I²C-Bus am RPi erkannt werden können. Mit dem Paket „i2c-tools“ [18] kann nach I²C-Geräten auf dem Bus gesucht werden. Entsprechend muss hier ein Gerät bei 0x20 und 0x27 gefunden werden. Um dies zu erreichen, wurden mit einem Oszilloskop die SDA- und SCL-Leitungen auf beiden Seiten der Pegelanpassung vermessen, entsprechende Fehler behoben und schlussendlich eine funktionierende Kommunikation verifiziert. Der Fokus bei dem Vorgehen war, ein gültiges SCL-Signal auf dem Bus zu sehen. Hierfür musste (wie in Abbildung 3.3 gesehen werden kann) die SCL-Leitung über Drähte neu angelötet werden. Hierbei war [19] eine große Hilfe beim Finden der I²C-Fehler. In Abbildung 4.1 kann der Testaufbau zur Verifikation der I2C-Kommunikation gesehen werden. Auf dem Oszilloskop sieht man die 5V Pegel des I²C-Bus nach dem Pegelwandler.

19

4. Testen


Abbildung 4.1.: Testbench zum Überprüfen der Funktionalität des I²C-Bus und der PCB

Die in Abbildung 4.2 gezeigte Cartridge basiert auf [20]. Hier wurden alle Komponenten entfernt und die Pads mit einem Header verbunden. Mit Hilfe dieser Catridge konnten die am Cartridge-Adapter anliegenden Signale sehr einfach getestet werden. Diese Platine wurde ebenfalls mit Hilfe des „PCB-Milling“-Verfahren realisiert, wobei alles überflüssige Kupfer entfernt wurde, da sonst die Cartride-Pins kurzgeschlossen worden wären. Der Aufbau wird in Abbildung 4.1 gezeigt.

20

4. Testen


(a) Layout | (b) PCB

Abbildung 4.2.: Debug Cartridge

In dem in Abbildung 4.1 gezeigten Testaufbau, können die Lese- und Schreibeoperationen der verschiedenen Pins der GPIO-Expander überprüft werden.
Zur Überprüfung der Schreibbefehle läuft auf dem Arduino Mega Microcontroller ein Logic Analyzer. Dieser liest alle 10 ms den logischen Zustand aller Pins aus und schreibt die Werte im CSV-Format über die serielle Schnittstelle an den Rechner. Auf diesem Recher können im Anschluss die CSV-Werte mit einem Python-Skript visuell dargestellt werden. Der Logic Analyzer kann hier [21] gefunden werden. Auf dem DUT (in Abbildung 4.1) läuft ein Programm, das nacheinander, im Abstand von 20 ms jeden Pin einzeln auf eine logische 1 schaltet (wr, rd, cs werden auf 0 geschaltet, da diese low-activ sind). Um ein funktionierendes Programm zu gewährleisten, muss entsprechend das Ändern aller Pins im Plot erkennbar sein.
Zur Überprüfung der Lesebefehle läuft auf dem Arduino Mega Microcontroller ein Programm, welches auf die Datenpins alle möglichen Kombinationen von 0x00 bis 0xFF schreibt. Diese werden auf dem RPi ausgelesen und die Abfolge der geschriebenen Bytes validiert.
Durch das Testen mit diesen Programmen konnten verschiedene Fehler (z. B. eine schlechte Verbindung beim Löten) erkannt und entsprechend behoben werden.
Im Anhang in Kapitel A kann das Messprotokoll zu den oben genannten Tests gefunden werden. Unter „Input Tester - Raspberry Pi“ (ab Zeile 3) können die ausgelesenen Datenbytes vom Arduino gesehen werden. Hierbei tritt einmal ein Bitfehler auf, was aber auch am Testprogramm liegen kann, da die später ausgelesenen Cartridges einwandfrei funktionieren. Unter „Output Tester - Arduino Logic Analyzer“ (ab Zeile 120) kann die CSV-Datei des Logic Analyzers gesehen werden. Hier sieht man, dass jeder Pin entsprechend beschrieben werden kann.

21

4. Testen

Nachdem die oben erwähnten Tests bestanden wurden, konnte das Auslesen von GameBoy-Cartridges getestet werden. Der Aufbau wird in Abbildung 4.3 gezeigt. Hierfür wurden die in Kapitel 3.2 erklärten Funktionen verwendet.


Abbildung 4.3.: Auslesen der Cartridges

22

# 5. Ergebnisse

Im Laufe des Projekts, konnte die am Anfang gestellte Zielsetzung erfüllt werden. Es wurde eine Platine erstellt, welche das Auslesen von GameBoy-Cartridges ermöglicht. Diese besitzt den Formfaktor eines GameBoy-Mainboards und kann somit in einem GameBoy-Zero eingebaut werden. Entsprechend befindet sich der Cartridge-Adapter an derselben Stelle wie beim originalen GameBoy. Um die GPIO-Pins des RPi zu erweitern, wurde ein Port-Expander, welcher über I²C mit dem RPi kommuniziert, verwendet. In Abbildung 5.1 können Screenshots gesehen werden, die bei der Emulation der ausgelesenen Cartridges aufgenommen wurden. Es konnten alle in Abbildung 2.3 gezeigten Cartridges ausgelesen werden. Da diese die verschiedenen MBC kein MBC, MBC1 und MBC5 hatten, kann davon ausgegangen werden, dass auch das Auslesen anderer Cartridges mit denselben Controllern ebenfalls funktionieren würde.


(a) Tetris | (b) Yoshi’s Cookie | (c) Pokémon TCG mit Speicherstand

Abbildung 5.1.: Emulation der ausgelesenen Cartridges

Des Weiteren gibt es einige Verbesserungsvorschläge. Mit der für die Kommunikation mit den MCP23017-ICs verwendete Bibliothek „WiringPi“ [12] kann jeder Pin nur über einen einzelnen Befehl beschrieben werden. Die ICs würden auch die Möglichkeit bieten, einen ganzen Port (8 Pins) jeweils mit einem Byte zu beschreiben. Dies wäre eine signifikante Zeitersparnis und würde das Auslesen deutlich beschleunigen. In der aktuellen Version wird für das Auslesen einer ROM-Bank eine Zeit von 4 min benötigt. Dies führt dazu, dass das Auslesen großer Cartridges mehrere Stunden dauern kann. Im Gegensatz dazu wird mit diesem Arduino Shield [15] nur eine Zeit von 7.7 s benötigt. Des Weiteren könnte der Prozess durch das Verwenden der SPI-Version des MCP23017

23

5. Ergebnisse

durch die wesentlichen höheren Transferraten noch weiter beschleunigt werden. Darüber hinaus gibt es einige Verbesserungen, die in die in Abbildung 3.1 gezeigte Schaltung bereits eingezeichnet wurden. Beim Testaufbau wurde ein Pegelwandler (siehe Abbildung 4.1) mit Pull-Up-Widerständen auf einem Steckbrett verwendet. Diese wurden nachträglich mit in die Schaltung und das Layout (siehe Abbildung
3.2) eingezeichnet. Außerdem wurde bei der gefrästen Platine die Konfiguration der I²C-Adresse der ICs vergessen und die Unter- und Oberseite der Mainboard-Vorlage vertauscht. Dies wurde ebenfalls ausgebessert.

24

# Literaturverzeichnis

[1] “Raspberry | Pi | Zero | W,” | https://www.raspberrypi.org/products/
raspberry-pi-zero-w/, (https://www.raspberrypi.org/products/raspberry-pi-zero-w/) Zugriff: 17.12.2020.
[2] “ZeroBoy: Geschichte,” https://www.zeroboy.eu/geschichte/, Zugriff: 05.12.2020.
[3] F. Weichselgartner, “GameBoy Zero,” https://felixweichselgartner.github.io/2019/01/29/GameBoy_Zero.html, (https://felixweichselgartner.github.io/2019/01/29/GameBoy_Zero.html) Zugriff: 12.12.2020.
[4] ——, | “GitHub: | GameBoy-Classic-Emulator,” | https://github.com/
FelixWeichselgartner/GameBoy-Classic-Emulator, (https://github.com/FelixWeichselgartner/GameBoy-Classic-Emulator) Zugriff: 07.12.2020.
[5] ——, “GB Cartridge Reader Writer,” https://felixweichselgartner.github.io/2019/09/01/GB_Cartridge_Reader_Writer.html, (https://felixweichselgartner.github.io/2019/09/01/GB_Cartridge_Reader_Writer.html) September 2019, Zugriff: 07.12.2020.
[6] MCP23017/MCP23S17: 16-Bit I/O Expander with Serial Interface, Microchip Technology Inc., 06 2016, https://ww1.microchip.com/downloads/en/DeviceDoc/20001952C.pdf. (https://ww1.microchip.com/downloads/en/DeviceDoc/20001952C.pdf)
[7] B. Byers, “Brendan’s Website: A Look at the Gameboy DMG,” https://b13rg.github.io/Gameboy_DMG/, (https://b13rg.github.io/Gameboy_DMG/) Zugriff: 06.12.2020.
[8] “Gameboy Development Wiki,” https://gbdev.gg8.se/wiki/articles/Main_Page, Zugriff: 06.12.2020.
[9] B. Byers, “Brendan’s Website: Gameboy DMG ROM and RAM Bank Switching,” https://b13rg.github.io/Gameboy-Bank-Switching/, Zugriff: 12.12.2020.
[10] “Gameboy Development Wiki: The Cartridge Header,” https://gbdev.gg8.se/wiki/articles/The_Cartridge_Header, (https://gbdev.gg8.se/wiki/articles/The_Cartridge_Header) Zugriff: 07.12.2020.
[11] B. Byers, “Brendan’s Website: Exploring the Gameboy Memory Bank Controller,” https://b13rg.github.io/Gameboy-MBC-Analysis/, Zugriff: 07.12.2020.
[12] “Wiring Pi - GPIO Interface library for the Raspberry Pi: I2C: MCP23008 & MCP23017,” http://wiringpi.com/extensions/i2c-mcp23008-mcp23017/, Zugriff: 05.12.2020.

25

Literaturverzeichnis

[13] “DMG-Rolf GameBoy schematics,” https://gbdev.gg8.se/files/schematics/DMG-Rolf/, (https://gbdev.gg8.se/files/schematics/DMG-Rolf/) Zugriff: 12.12.2020.
[14] “Attribution-NonCommercial-ShareAlike 2.5 Canada (CC BY-NC-SA 2.5 CA),” https://creativecommons.org/licenses/by-nc-sa/2.5/ca/, Zugriff: 12.12.2020.
[15] F. Weichselgartner, “GitHub: GB-Cartridge-Reader-Writer,” https://github.com/FelixWeichselgartner/GB-Cartridge-Reader-Writer, (https://github.com/FelixWeichselgartner/GB-Cartridge-Reader-Writer) Zugriff: 07.12.2020.
[16] ——, “GB Cartridge Reader Writer continued,” https://felixweichselgartner.github.io/2020/11/28/GB_Cartridge_Reader_Writer_continued.html, (https://felixweichselgartner.github.io/2020/11/28/GB_Cartridge_Reader_Writer_continued.html) November 2020, Zugriff: 07.12.2020.
[17] “GBCartRead – Gameboy Cart Reader,” https://github.com/insidegadgets/GBCartRead, (https://github.com/insidegadgets/GBCartRead) Zugriff: 25.12.2020.
[18] “Paket: i2c-tools (3.1.2-3) - Heterogener I2C-Werkzeugsatz für Linux,” https://packages.debian.org/de/stretch/i2c-tools, Zugriff: 24.12.2020.
[19] “The | Problems | of | I2C | - | common | problems | and | errors
with | using | I2C,” | https://www.microforum.cc/blogs/entry/
42-the-problems-of-i2c-common-problems-and-errors-with-using-i2c, (https://www.microforum.cc/blogs/entry/42-the-problems-of-i2c-common-problems-and-errors-with-using-i2c) Zugriff: 25.12.2020.
[20] “Xyl2k - Homebrew Gameboy Color Cartridge,” https://github.com/Xyl2k/Gameboy-Color-Cartridge, (https://github.com/Xyl2k/Gameboy-Color-Cartridge) Zugriff: 19.12.2020.
[21] F. Weichselgartner, “GitHub: Arduino_Logic_Analyzer,” https://github.com/FelixWeichselgartner/Arduino_Logic_Analyzer, (https://github.com/FelixWeichselgartner/Arduino_Logic_Analyzer) Zugriff: 07.12.2020.

26

# Abbildungsverzeichnis

2.1. DMG Frontansicht und Mainboard | | 2
2.2. Blockschaltbild des DMG | | 3
2.3. Frontansichten der verwendeten Cartridges | | 7
2.4. Rückansichten der verwendeten Cartridges | | 7
2.5. Cartridge Pinout | | 8
2.6. Cartridge Adapter | | 9
2.7. Pinout des MCP23017 | | 9
2.8. Blockschaltbild des MCP23017 | | 10
2.9. Testaufbau des MCP23017 an einem Raspberry Pi 3B+ | | 11
2.10. Bidirektionale Pegelwandlerschaltung mit einem MOSFET | | 11
3.1. Schaltplan des PCB | | 12
3.2. Layout des PCB | | 13
3.3. Leiterplatte | | 14
3.4. Lesen von Bytes von der Cartridge | | 15
3.5. Schreiben von Bytes zur Cartridge | | 16
3.6. Auslesen von ROM | | 17
3.7. Auslesen von RAM | | 18
4.1. Testbench zum Überprüfen der Funktionalität des I²C-Bus und der PCB | 20
4.2. Debug Cartridge | | 21
4.3. Auslesen der Cartridges | | 22
5.1. Emulation der ausgelesenen Cartridge | | 23

27

# Tabellenverzeichnis

2.1. Memory Map des DMG | | 3
2.2. Memory Map des Cartridge Headers | | 4
2.3. Cartridge Header: Cartridge Typ | | 5
2.4. Cartridge Header: ROM Größe | | 6
2.5. Cartridge Header: RAM Größe | | 6

28

# Abkürzungsverzeichnis

DMG Originaler GameBoy, Klassischer GameBoy

MBC Memory Bank Controller

ROM Read Only Memory

RAM Random Access Memory

IC Integrated Circuit

I²C Inter-Integrated Circuit

SPI Serial Peripheral Interface

RPi Raspberry Pi

DUT Device Under Test

CSV Comma Separated Values

29
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

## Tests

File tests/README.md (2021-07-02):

# Debug

This folder contains programs and hardware that can help with debugging the project:
* `debug_cartridge/` includes a pcb that can be used to test if the cartridge interface is working.
* `cartridge_pin_tester/` includes programs to test the input and output of the cartridge interface.
* `gpio_tester/` includes programs to test mcp23017 in general
* `roms/` includes programs to compare or look at roms.

# Licensing

All licensed unter `LICENSE.md`.

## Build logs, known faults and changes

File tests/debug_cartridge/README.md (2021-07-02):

 # Debug Cartridge

 Cartridge used to debug the cartridge-pcb. Further, it can also be used to emulate a cartridge.
 
 Based on https://github.com/Xyl2k/Gameboy-Color-Cartridge with License (Unlicense) https://github.com/Xyl2k/Gameboy-Color-Cartridge/blob/master/LICENSE

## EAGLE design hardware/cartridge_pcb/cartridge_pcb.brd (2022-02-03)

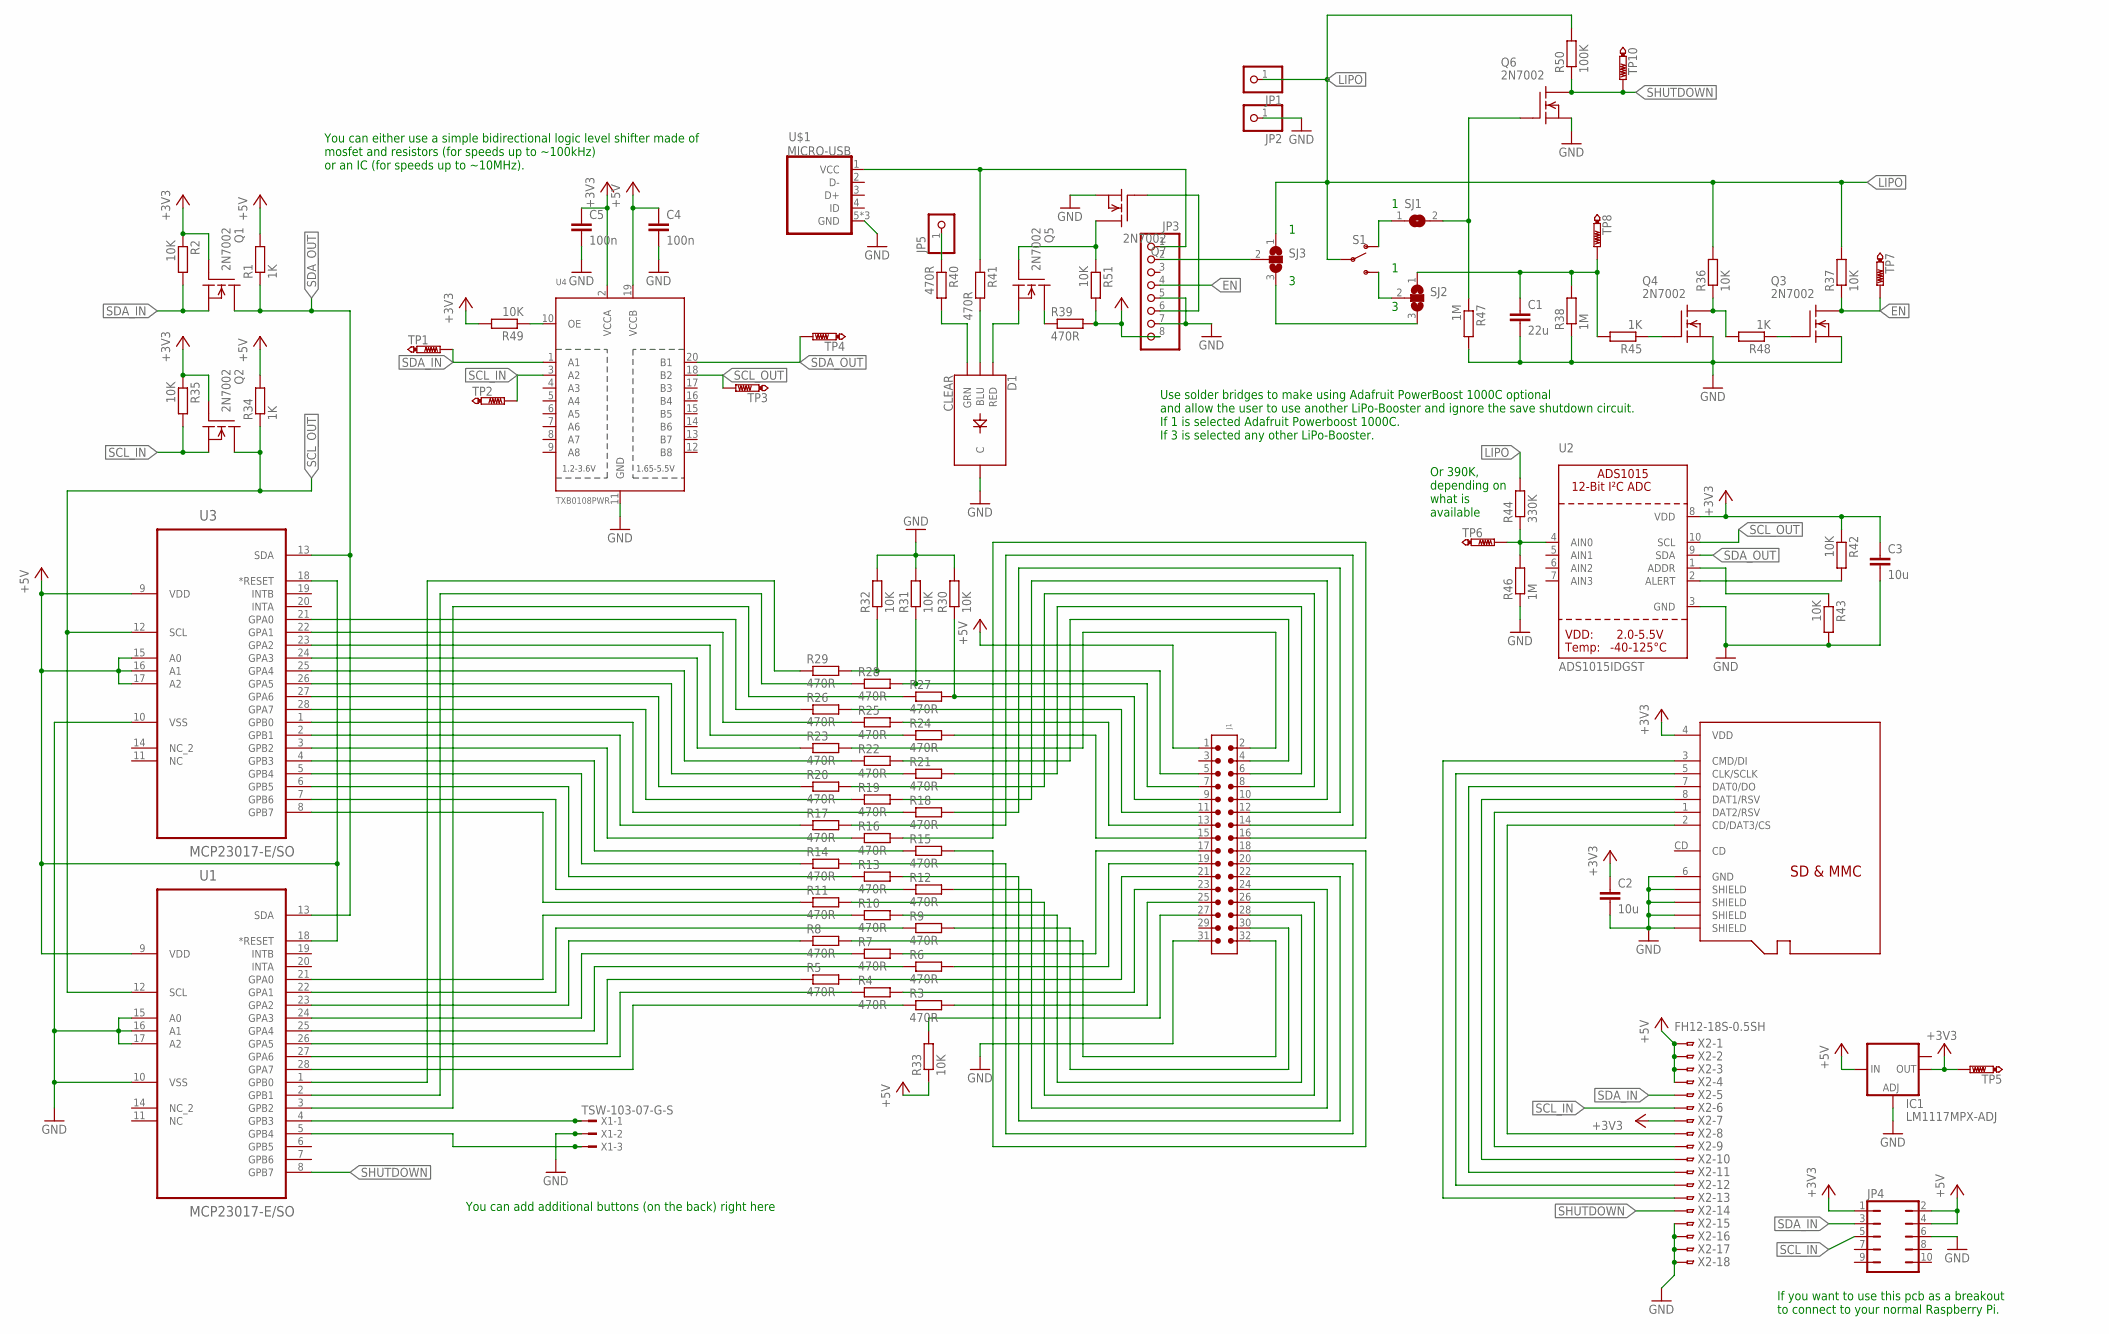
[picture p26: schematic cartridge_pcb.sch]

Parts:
C1: 22u; C0805
C2, C3: 10u; C0805
C4, C5: 100n; C0805
D1: CLEAR; LED-RGB-THRU
IC1: LM1117MPX-ADJ; SOT223
J1: 6130XX21121_61303221121; 61303221121
JP1, JP2, JP5: PINHD-1X1; 1X01
JP3: HEADER-1X8ROUND; 1X08_ROUND
JP4: JP5Q
Q1, Q2, Q3, Q4, Q5, Q6, Q7: 2N7002; SOT23
R1, R34, R45, R48: 1K; R0805
R2, R30, R31, R32, R33, R35, R36, R37, R42, R43, R49, R51: 10K; R0805
R3, R4, R5, R6, R7, R8, R9, R10, R11, R12, R13, R14, R15, R16, R17, R18, R19, R20, R21, R22, R23, R24, R25, R26, R27, R28, R29, R39, R40, R41: 470R; R0805
R38, R46, R47: 1M; R0805
R44: 330K; R0805
R50: 100K; R0805
S1: SWITCH-SPDT-PTH-8.6X4.3MM-LOCK; SWITCH_SPDT_8.6X4.3MM_LOCK
SJ1: SJ
SJ2, SJ3: SJ2W; SJ_2
TP1, TP2, TP3, TP4, TP5, TP6, TP7, TP8, TP10: PTR1TP10R; TP10R
U1, U3: MCP23017-E/SO; SOIC127P1032X265-28N
U2: ADS1015IDGST; MSOP10
U4: TXB0108PWR; TSSOP20
U$1: MICRO-USB
U$2: MICROSD; C12075
X1: TSW-103-07-G-S; TSW-103-XX-G-S
X2: FH12-18S-0.5SH

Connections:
+3V3: C2.1, C3.1, C5.1, IC1.2 (OUT), JP4.1, Q1.1 (G), Q2.1 (G), R2.1, R35.1, R42.1, R49.2, TP5.TP, U2.8 (VDD), U4.2 (VCCA), U$2.4 (VDD), X2.7
+5V: C4.1, IC1.3 (IN), J1.1, JP3.8, JP4.2, JP4.4, R1.2, R33.1, R34.2, R39.2, R51.2, U1.9 (VDD), U1.18 (*RESET), U3.9 (VDD), U3.15 (A0), U3.16 (A1), U3.17 (A2), U3.18 (*RESET), U4.19 (VCCB), X2.1, X2.2, X2.3, X2.4
EN: JP3.4, Q3.3 (D), R37.1, TP7.TP
GND: C1.2, C2.2, C3.2, C4.2, C5.2, D1.2 (C), IC1.1 (ADJ), J1.31, JP2.1, JP3.5, JP3.7, JP4.6, Q3.2 (S), Q4.2 (S), Q6.2 (S), Q7.2 (S), R30.2, R31.2, R32.2, R38.1, R43.2, R46.1, R47.2, U1.10 (VSS), U1.15 (A0), U1.16 (A1), U1.17 (A2), U2.3 (GND), U3.10 (VSS), U4.11 (GND), U$1.5 (GND), U$1.GND1 (GND), U$1.GND2 (GND), U$2.6 (GND), U$2.GND@1 (SHIELD), U$2.GND@2 (SHIELD), U$2.GND@3 (SHIELD), U$2.GND@4 (SHIELD), X1.2, X2.15, X2.16, X2.17, X2.18
LIPO: JP1.1, R36.2, R37.2, R44.2, R50.2, S1.2, SJ3.1
unnamed: R12.1, U3.7 (GPB6)
unnamed: R11.1, U3.8 (GPB7)
unnamed: R10.1, U1.21 (GPA0)
unnamed: R3.1, U1.28 (GPA7)
unnamed: R13.1, U3.6 (GPB5)
unnamed: R14.1, U3.5 (GPB4)
unnamed: R15.1, U3.4 (GPB3)
unnamed: R16.1, U3.3 (GPB2)
unnamed: R17.1, U3.2 (GPB1)
unnamed: R18.1, U3.1 (GPB0)
unnamed: R19.1, U3.28 (GPA7)
unnamed: R20.1, U3.27 (GPA6)
unnamed: R21.1, U3.26 (GPA5)
unnamed: R22.1, U3.25 (GPA4)
unnamed: R23.1, U3.24 (GPA3)
unnamed: R24.1, U3.23 (GPA2)
unnamed: R25.1, U3.22 (GPA1)
unnamed: R26.1, U3.21 (GPA0)
unnamed: R9.1, U1.22 (GPA1)
unnamed: R8.1, U1.23 (GPA2)
unnamed: R7.1, U1.24 (GPA3)
unnamed: R6.1, U1.25 (GPA4)
unnamed: R5.1, U1.26 (GPA5)
unnamed: R4.1, U1.27 (GPA6)
unnamed: J1.25, R3.2
unnamed: J1.23, R4.2
unnamed: J1.19, R6.2
unnamed: J1.21, R5.2
unnamed: J1.32, R8.2
unnamed: J1.30, R9.2
unnamed: J1.28, R10.2
unnamed: J1.26, R11.2
unnamed: J1.24, R12.2
unnamed: J1.22, R13.2
unnamed: J1.20, R14.2
unnamed: J1.18, R15.2
unnamed: J1.16, R16.2
unnamed: J1.14, R17.2
unnamed: J1.12, R18.2
unnamed: J1.10, R19.2
unnamed: J1.8, R20.2
unnamed: J1.6, R21.2
unnamed: J1.11, R26.2
unnamed: J1.13, R25.2
unnamed: J1.15, R24.2
unnamed: Q5.1 (G), Q7.3 (D), R51.1
unnamed: J1.17, R7.2
unnamed: J1.9, R27.2, R30.1
unnamed: J1.2, R23.2
unnamed: J1.5, R29.2, R32.1
unnamed: J1.27, R33.2
unnamed: R44.1, R46.2, TP6.TP, U2.4 (AIN0)
unnamed: R43.1, U2.1 (ADDR)
unnamed: U$2.7 (DAT0/DO), X2.11
unnamed: J1.4, R22.2
unnamed: JP3.6, Q7.1 (G)
unnamed: R27.1, U1.3 (GPB2)
unnamed: R28.1, U1.2 (GPB1)
unnamed: R29.1, U1.1 (GPB0)
unnamed: U$2.8 (DAT1/RSV), X2.10
unnamed: U$2.1 (DAT2/RSV), X2.9
unnamed: Q4.3 (D), R36.1, R48.2
unnamed: JP5.1, R40.1
unnamed: U$2.2 (CD/DAT3/CS), X2.8
unnamed: C1.1, R38.2, R45.2, SJ2.1, TP8.TP
unnamed: U$2.5 (CLK/SCLK), X2.12
unnamed: U$2.3 (CMD/DI), X2.13
unnamed: Q5.3 (D), R39.1
unnamed: J1.7, R28.2, R31.1
unnamed: D1.4 (BLU), R41.2
unnamed: D1.3 (GRN), R40.2
unnamed: D1.1 (RED), Q5.2 (S)
unnamed: Q3.1 (G), R48.1
unnamed: R42.2, U2.2 (ALERT)
unnamed: Q4.1 (G), R45.1
unnamed: S1.3 (S), SJ2.2
unnamed: S1.1 (O), SJ1.1
unnamed: JP3.2, SJ3.2
unnamed: SJ2.3, SJ3.3
unnamed: JP3.1, R41.1, U$1.1 (VCC)
unnamed: R49.1, U4.10 (OE)
unnamed: U1.4 (GPB3), X1.1
unnamed: U1.5 (GPB4), X1.3
SCL_IN: JP4.5, Q2.2 (S), R35.2, TP2.TP, U4.3 (A2), X2.6
SCL_OUT: Q2.3 (D), R34.1, TP3.TP, U1.12 (SCL), U2.10 (SCL), U3.12 (SCL), U4.18 (B2)
SDA_IN: JP4.3, Q1.2 (S), R2.2, TP1.TP, U4.1 (A1), X2.5
SDA_OUT: Q1.3 (D), R1.1, TP4.TP, U1.13 (SDA), U2.9 (SDA), U3.13 (SDA), U4.20 (B1)
SHUTDOWN: Q6.3 (D), R50.1, TP10.TP, U1.8 (GPB7), X2.14
SHUTDOWN_OLD: Q6.1 (G), R47.1, SJ1.2

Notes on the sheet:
Use solder bridges to make using Adafruit PowerBoost 1000C optional and allow the user to use another LiPo-Booster and ignore the save shutdown circuit. If 1 is selected Adafruit Powerboost 1000C. If 3 is selected any other LiPo-Booster.
You can either use a simple bidirectional logic level shifter made of mosfet and resistors (for speeds up to ~100kHz) or an IC (for speeds up to ~10MHz).
You can add additional buttons (on the back) right here
If you want to use this pcb as a breakout to connect to your normal Raspberry Pi.
Or 390K, depending on what is available

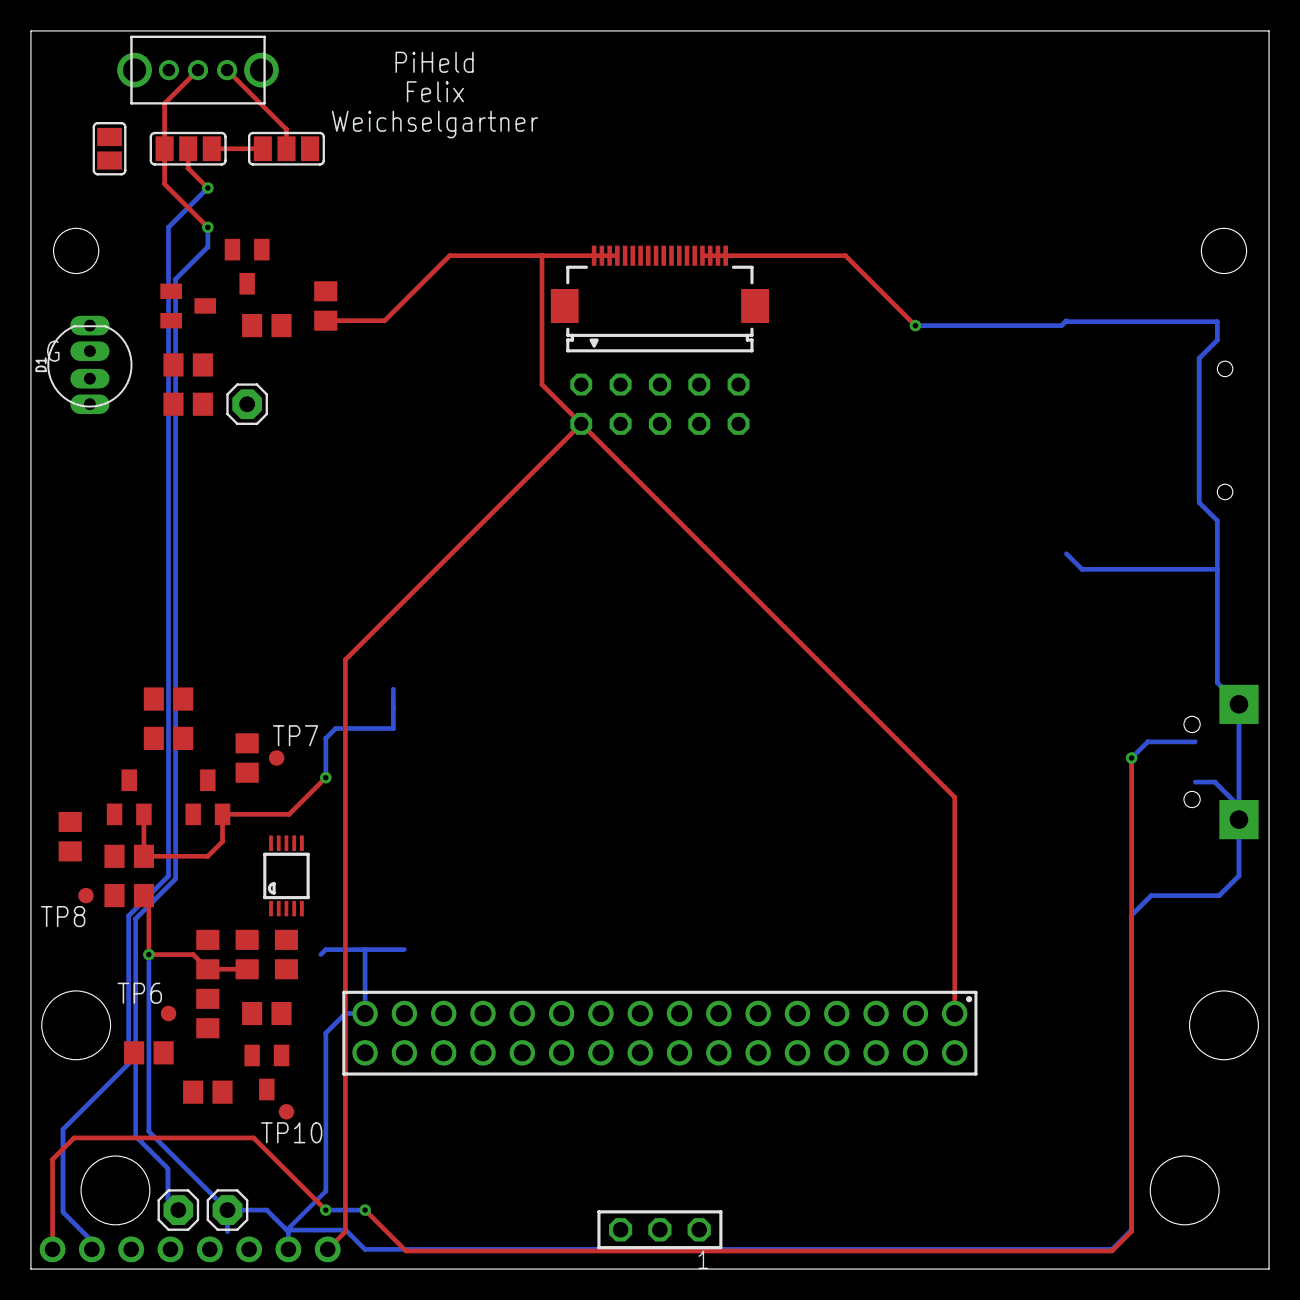
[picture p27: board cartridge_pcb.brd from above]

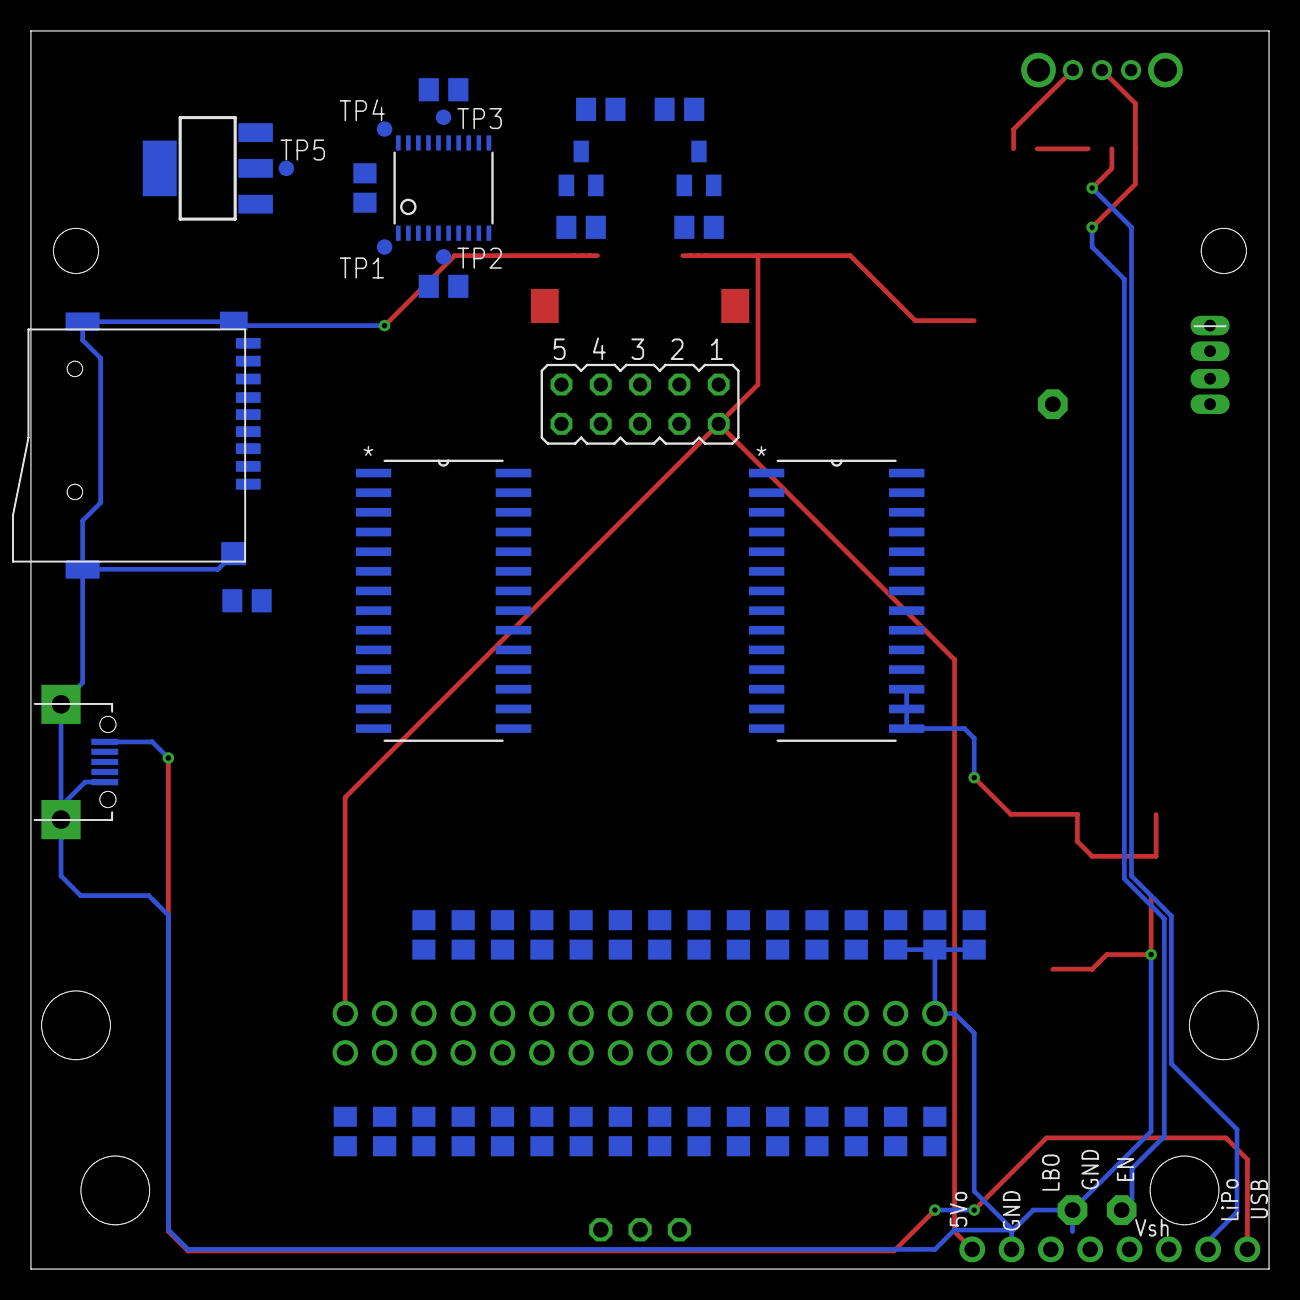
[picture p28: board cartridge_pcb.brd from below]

Board: 2 copper layers, 80.0 x 80.0 mm, 92 parts (53 on the bottom side), 94 nets.

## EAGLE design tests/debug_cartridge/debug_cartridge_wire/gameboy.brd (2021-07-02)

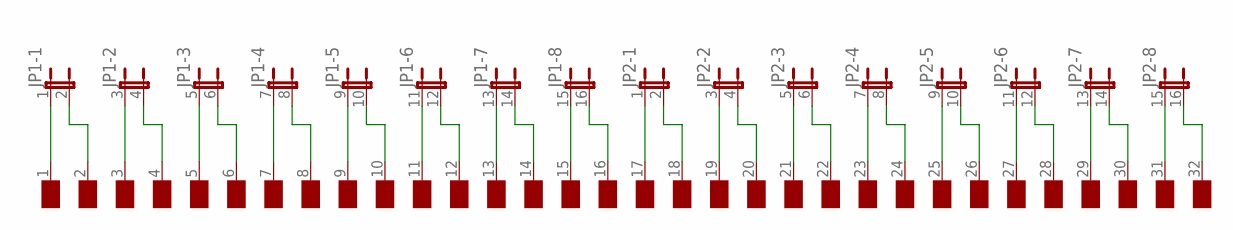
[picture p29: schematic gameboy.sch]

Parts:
JP1, JP2: JP8QE; JP8Q
U$1: CONNECTOR

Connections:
unnamed: JP1.1, U$1.1 (VDD)
unnamed: JP1.2, U$1.2 (NC)
unnamed: JP1.3 (1), U$1.3 (/WR)
unnamed: JP1.4 (2), U$1.4 (/RD)
unnamed: JP1.5 (1), U$1.5 (/RCS)
unnamed: JP1.6 (2), U$1.6 (A0)
unnamed: JP1.7 (1), U$1.7 (A1)
unnamed: JP1.8 (2), U$1.8 (A2)
unnamed: JP1.9 (1), U$1.9 (A3)
unnamed: JP1.10 (2), U$1.10 (A4)
unnamed: JP1.11 (1), U$1.11 (A5)
unnamed: JP1.12 (2), U$1.12 (A6)
unnamed: JP1.13 (1), U$1.13 (A7)
unnamed: JP1.14 (2), U$1.14 (A8)
unnamed: JP1.15 (1), U$1.15 (A9)
unnamed: JP1.16 (2), U$1.16 (A10)
unnamed: JP2.1, U$1.17 (A11)
unnamed: JP2.2, U$1.18 (A12)
unnamed: JP2.3 (1), U$1.19 (A13)
unnamed: JP2.4 (2), U$1.20 (A14)
unnamed: JP2.5 (1), U$1.21 (A15)
unnamed: JP2.6 (2), U$1.22 (D0)
unnamed: JP2.7 (1), U$1.23 (D1)
unnamed: JP2.8 (2), U$1.24 (D2)
unnamed: JP2.9 (1), U$1.25 (D3)
unnamed: JP2.10 (2), U$1.26 (D4)
unnamed: JP2.11 (1), U$1.27 (D5)
unnamed: JP2.12 (2), U$1.28 (D6)
unnamed: JP2.13 (1), U$1.29 (D7)
unnamed: JP2.14 (2), U$1.30 (/RS)
unnamed: JP2.15 (1), U$1.31 (VIN)
unnamed: JP2.16 (2), U$1.32 (GND)

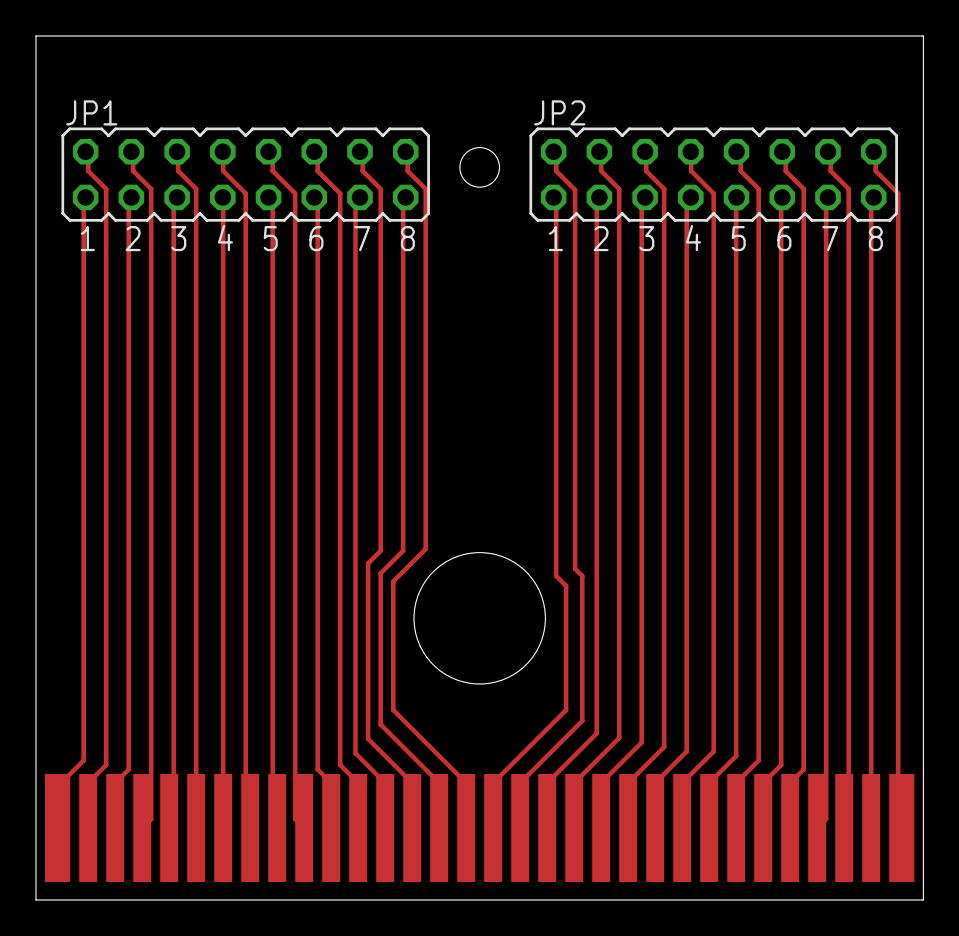
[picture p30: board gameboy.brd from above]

Board: 2 copper layers, 49.3 x 48.0 mm, 3 parts (0 on the bottom side), 32 nets.

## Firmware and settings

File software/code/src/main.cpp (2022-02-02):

#include "Cartridge.hpp"

#include <iostream>
using namespace std;

#include "format.hpp"

#include <chrono>
#include <ctime>    


int main() {
    cout << "== START ==" << endl;

    auto start = chrono::system_clock::now();
  
    Cartridge cartridge = Cartridge();
    cartridge.ReadHeader();
    cartridge.printHeader();
    
    cartridge.DumpROM();

    auto end = chrono::system_clock::now();
    chrono::duration<double> elapsed_seconds = end-start;
    time_t end_time = chrono::system_clock::to_time_t(end);
    cout << "finished computation at " << ctime(&end_time)
         << "elapsed time: " << elapsed_seconds.count() << "s\n";
    
    cartridge.DumpRAM();
    
    cout << "==  END  ==" << endl;

    return 0;
}

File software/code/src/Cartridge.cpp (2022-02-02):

#include "Cartridge.hpp"
#include "format.hpp"

Byte nintendoLogo[] = {
    0xCE, 0xED, 0x66, 0x66, 0xCC, 0x0D, 0x00, 0x0B, 0x03, 0x73, 0x00, 0x83, 0x00, 0x0C, 0x00, 0x0D,
    0x00, 0x08, 0x11, 0x1F, 0x88, 0x89, 0x00, 0x0E, 0xDC, 0xCC, 0x6E, 0xE6, 0xDD, 0xDD, 0xD9, 0x99,
    0xBB, 0xBB, 0x67, 0x63, 0x6E, 0x0E, 0xEC, 0xCC, 0xDD, 0xDC, 0x99, 0x9F, 0xBB, 0xB9, 0x33, 0x3E
};

void Cartridge::reset() {
    this->cartridgeType = 0;
    this->romSize = 0;
    this->romBanks = 0;
    this->ramSize = 0;
    this->ramBanks = 0;
    this->ramEndAddress = 0;

    this->gpio.dataInput();

    this->gpio.wr_high();
    this->gpio.rd_high();
    this->gpio.cs_high();
}

Cartridge::Cartridge() { 
    this->reset();
}

Cartridge::~Cartridge() {
    if (rom_array != nullptr)
        delete this->rom_array;
    if (ram_array != nullptr)
        delete this->ram_array;
}

void Cartridge::ReadHeader() {
    this->gpio.wr_high();
    this->gpio.rd_high();
    this->gpio.cs_high();

    // Read Cartridge Header
    for (int addr = 0x0134; addr <= 0x143; addr++) {
        char headerChar = (char) this->gpio.getByte(addr);
        if ((headerChar >= 0x30 && headerChar <= 0x57) || // 0-9
            (headerChar >= 0x41 && headerChar <= 0x5A) || // A-Z
            (headerChar >= 0x61 && headerChar <= 0x7A)) { // a-z
            this->gameTitle[(addr - 0x0134)] = headerChar;
        }
    }
    this->gameTitle[16] = '\0';

    // Nintendo Logo Check
    this->logoCheck = true;
    Byte x = 0;
    for (Word romAddress = 0x0104; romAddress <= 0x133; romAddress++) {
        if (nintendoLogo[x] != this->gpio.getByte(romAddress)) {
            this->logoCheck = false;
            break;
        }
        x++;
    }

    this->cartridgeType = this->gpio.getByte(0x0147);
    this->romSize = this->gpio.getByte(0x0148);
    this->ramSize = this->gpio.getByte(0x0149);

    // ROM banks
    this->romBanks = 2; // Default 32K
    if (this->romSize >= 1) { // Calculate rom size
        this->romBanks = 2 << this->romSize;
    }

    // RAM banks
    this->ramBanks = 0; // Default 0K RAM
    if (this->cartridgeType == 6) { this->ramBanks = 1; }
    switch(this->ramSize) {
        case 2: this->ramBanks = 1; break;
        case 3: this->ramBanks = 4; break;
        case 4: this->ramBanks = 16; break;  // GB Camera
        case 5: this->ramBanks = 8; break;
    }

    // RAM end address
    if (this->cartridgeType == 6) { this->ramEndAddress = 0xA1FF; } // MBC2 512bytes (nibbles)
    if (this->ramSize == 1) { this->ramEndAddress = 0xA7FF; } // 2K RAM
    if (this->ramSize > 1) { this->ramEndAddress = 0xBFFF; } // 8K RAM
}

void Cartridge::DumpROM() {
    cout << "== DUMPING ROM ==" << endl;
    rom_array = new char[romBanks * 0x4000];
    if (rom_array == NULL) {
        cout << "could not reserve heap memory for dump" << endl;
        return;
    }

    this->gpio.wr_high();
    this->gpio.rd_high();
    this->gpio.cs_high();
    
    Word addr = 0;

    cout << "0";
    
    // Read number of banks and switch banks
    for (Word bank = 1; bank < this->romBanks; bank++) {
        if (this->cartridgeType >= 5) { // MBC2 and above
            this->gpio.setByte(0x2100, bank & 0xFF); // Set ROM bank
            this->gpio.setByte(0x3000, bank > 0x100 ? 0x01 : 0x00);
        } else { // MBC1
            this->gpio.setByte(0x6000, 0); // Set ROM Mode 
            this->gpio.setByte(0x4000, bank >> 5); // Set bits 5 & 6 (01100000) of ROM bank
            this->gpio.setByte(0x2000, bank & 0x1F); // Set bits 0 & 4 (00011111) of ROM bank
        }
        if (bank > 1) { addr = 0x4000; }

        for (; addr <= 0x7FFF; addr++) {
            rom_array[addr + 0x4000 * (bank - 1)] = this->gpio.getByte(addr);

            // show user that the program is still running
            if (addr % 0x0100 == 0) {
                cout << "#";
                cout << flush;
            }
            if (addr == 0x4000) {
                cout << bank;
                cout << flush;
            }
        }
    }
    cout << endl;

    // write rom_array to file
    streampos size;
    ofstream gbfile;

    string romFileName = /*(string)this->gameTitle*/ "somename.gb";
    gbfile.open(romFileName, ios::out | ios::binary | ios::ate);

    if (gbfile.is_open()) {
        gbfile.write(rom_array, romBanks * 0x4000);
        gbfile.close();
    } else {
        cout << "couldn't reserve enough memory" << endl;
        exit(1);
    }

    cout << "== ROM DUMPED TO: " << romFileName << " ==" << endl;
}

void Cartridge::DumpRAM() {
    cout << "== DUMPING RAM ==" << endl;

    this->gpio.wr_high();
    this->gpio.rd_high();
    this->gpio.cs_high();

    // MBC2 Fix (unknown why this fixes it, maybe has to read ROM before RAM?)
    this->gpio.getByte(0x0134);
    
    // Does cartridge have RAM
    if (this->ramEndAddress > 0) {
        ram_array = new char[this->ramBanks * 0x2000];

        if (cartridgeType <= 4) { // MBC1
            this->gpio.setByte(0x6000, 1); // Set RAM Mode
        }

        // Initialise MBC
        this->gpio.setByte(0x0000, 0x0A);

        // Switch RAM banks
        for (Byte bank = 0; bank < this->ramBanks; bank++) {
            this->gpio.setByte(0x4000, bank);

            // Read RAM
            for (unsigned int addr = 0xA000; addr <= this->ramEndAddress; addr++) {  
                ram_array[addr - 0xA000 + bank * 0x2000] = this->gpio.getByte(addr);

                if (addr % 0x1000 == 0) {
                    cout << "#";
                }
                if (addr == 0xA000) {
                    cout << bank;
                }
            }
        }
        
        // Disable RAM
        this->gpio.setByte(0x0000, 0x00);

        // write rom_array to file
        streampos size;
        ofstream gbfile;

        //string ramFileName = (string)this->gameTitle + ".sav";
        string ramFileName = /*(string)this->gameTitle*/ "somename.sav";
        gbfile.open(ramFileName, ios::out | ios::binary | ios::ate);

        if (gbfile.is_open()) {
            gbfile.write(ram_array, this->ramBanks * 0x2000);
            gbfile.close();
        } else {
            cout << "couldn't reserve enough memory" << endl;
            exit(1);
        }
        cout << "== RAM DUMPED TO: " << ramFileName << " ==" << endl;
    } else {
        cout << "== CARTRIDGE HAS NO RAM ==" << endl;
    }
}
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

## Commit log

2021-07-02 initial commit with cartridge pcb
    [cartridge_breakout.brd, cartridge_breakout.sch, cartridge_pcb.brd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]
2021-08-29 fix some issues of the cartridge pcb
    [cartridge_pcb.brd, cartridge_pcb.sch]
2021-10-11 fix more errors in cartridge pcb which were found while testing the cartridge reader
    [cartridge_pcb.brd, cartridge_pcb.sch]
2021-10-17 400kHz rom dumping working
    [config.txt]
2021-11-07 LiPo ADC management
2022-02-01 labeled debug cartridge; updated schem/layout image of last revision pcbs
    [gameboy.brd]
2022-02-02 integrated own mcp23017 library version instead of wiring pi
2022-02-03 fixed error in cpcb
    [cartridge_pcb.brd, cartridge_pcb.sch]

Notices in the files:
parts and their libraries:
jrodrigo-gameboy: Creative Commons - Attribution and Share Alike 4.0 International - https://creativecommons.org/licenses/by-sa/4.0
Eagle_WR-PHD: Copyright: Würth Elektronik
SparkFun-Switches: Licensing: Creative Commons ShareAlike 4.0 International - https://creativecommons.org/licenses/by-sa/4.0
